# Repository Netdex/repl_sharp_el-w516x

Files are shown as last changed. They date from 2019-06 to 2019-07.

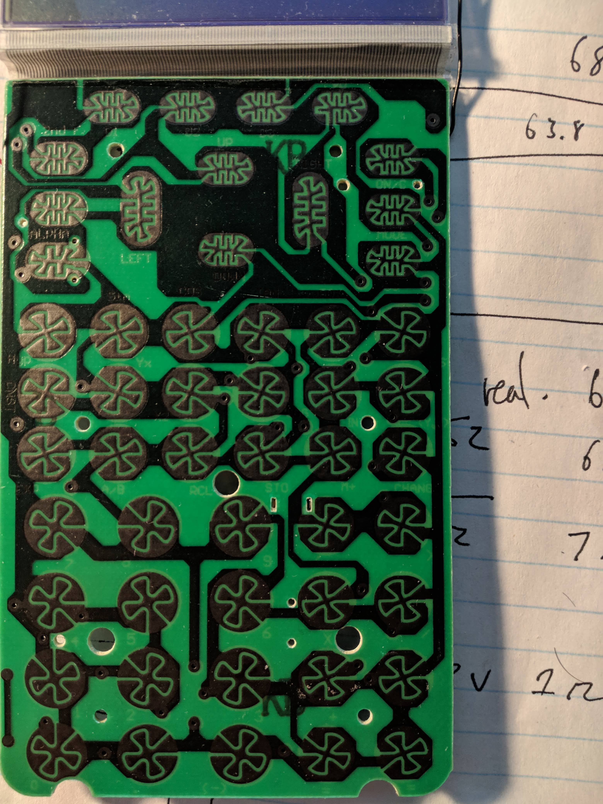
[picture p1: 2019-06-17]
IMG_20190607_183955.jpg

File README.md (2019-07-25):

# repl_sharp_el-w516x
`This project is a work-in-progress.`



## Overview
repl_sharp_el-w516x is a design for a replacement logic board for the SHARP EL-W516X calculator.



## Design
The goal of this project is to create a more powerful/elegant calculator out of as many components from the original 
calculator as possible.

This design reuses all components of the calculator except the following:
- Solar panel
  - It does not deliver enough power regardless
- Display
  - Connector pitch is too fine, and flex cable is too fragile
  - There are about 100 pins on the connector, and it requires a application-specific driver
  - The display is replaced with the [NHD-C12832A1Z-FSW-FBW-3V3](http://www.newhavendisplay.com/specs/NHD-C12832A1Z-FSW-FBW-3V3.pdf)
- PCB
- Battery
  - The original battery is an LR44 coin cell watch battery, which does not deliver the power required
  - The battery is replaced with a Samsung 3.8V Li-ion battery 

### Key matrix



The original calculator uses a carbon-coated silicone pad with carbon contacts on the PCB. This design uses the exact 
button pad footprint of the original calculator, with copper contacts instead.

The keys are arranged in a matrix, with a serial-in-parallel-out shift register on the rows, and a 
parallel-in-serial-out shift register on the columns. The microcontroller polls row and column pairs to detect 
key presses. Each column has a diode to avoid sinking 3V3 to GND when two buttons in the same row are pressed. 
In the case of multiple keys presed at once, ghosting will occur since diodes are only placed on a column-basis.

### Power delivery



The board is powered by a battery management IC with power path. The IC upregulates the battery voltage to +BATT + 250mV as VCC, 
where +BATT can vary from 3.0V (depleted) to 4.35V (full). An additional LDO regulates VCC to 3V3, which powers the 
microcontroller and other circuitry. The LDO has a dropout voltage of +250mV, which means that the battery will still 
have a bit of power left when it is depleted. The battery management IC actually charges to CV 4.2V, which means it 
will not charge the battery to full capacity (~80-90%).

The board can be charged via USB, which is also used for programming the microcontroller and other data transfer. 
Charging can occur while the device is being used, due to the power path management provided by the battery management 
IC. The battery charging current will automatically be ducked if the system power path draws too much power, to 
maintain system function. 

### uC
An ATMEGA32U4 microcontroller controls the display, input polling via shift registers, and computation. It is 
programmable via USB interface (factory ships with bootloader). ICSP is exposed via pads if required. 

Since the uC is powered by 3V3, an external 8 MHz oscillator provides the clock source.

## BOM
[InteractiveHtmlBom](https://raw.githack.com/Netdex/repl_sharp_el-w516x/master/kicad/bom/ibom.html)

## Pictures
3D Renders




Populated board (still covered in flux)



Front, in enclosure



Back, in enclosure (I need to file down the jagged edges)



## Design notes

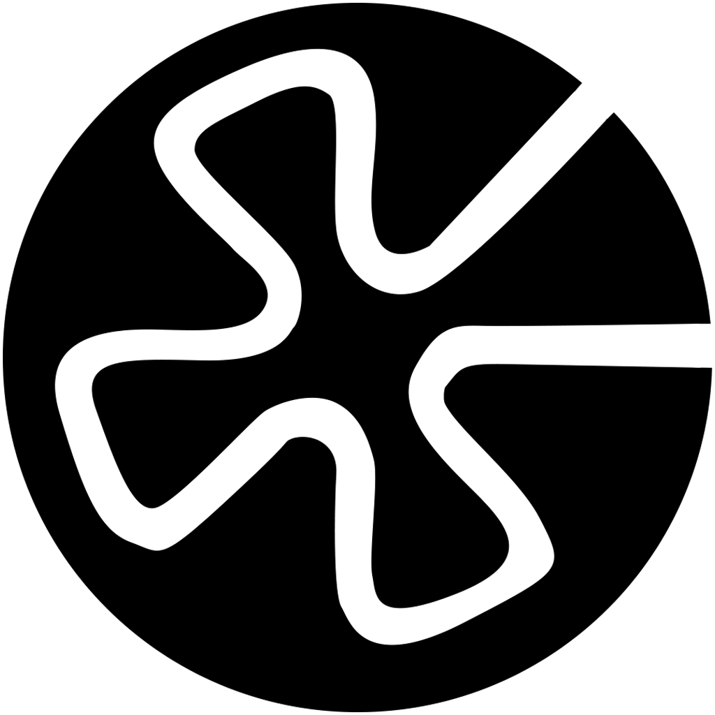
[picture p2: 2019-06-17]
btn_circular.png

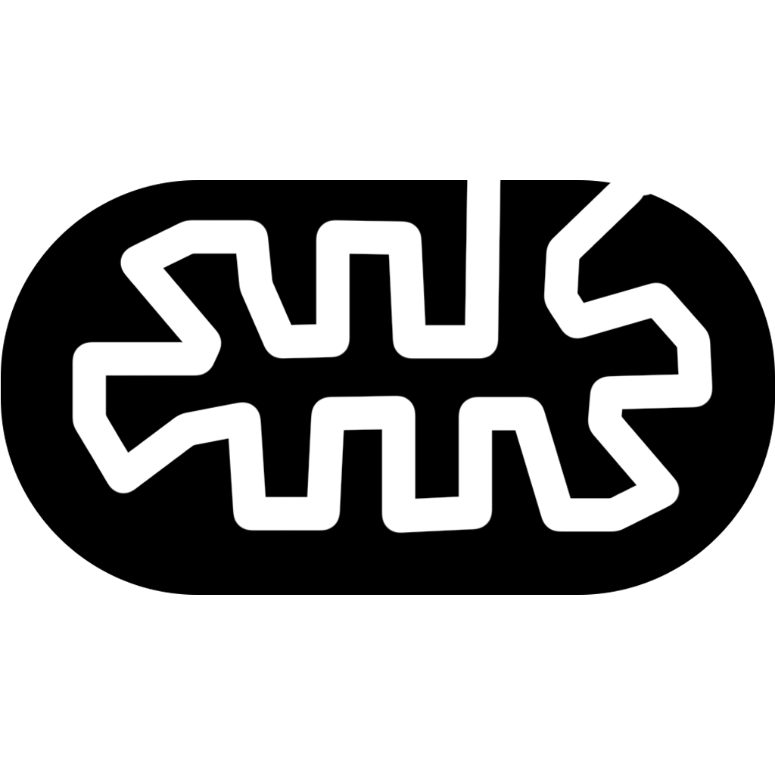
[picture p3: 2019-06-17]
btn_long_rect.png

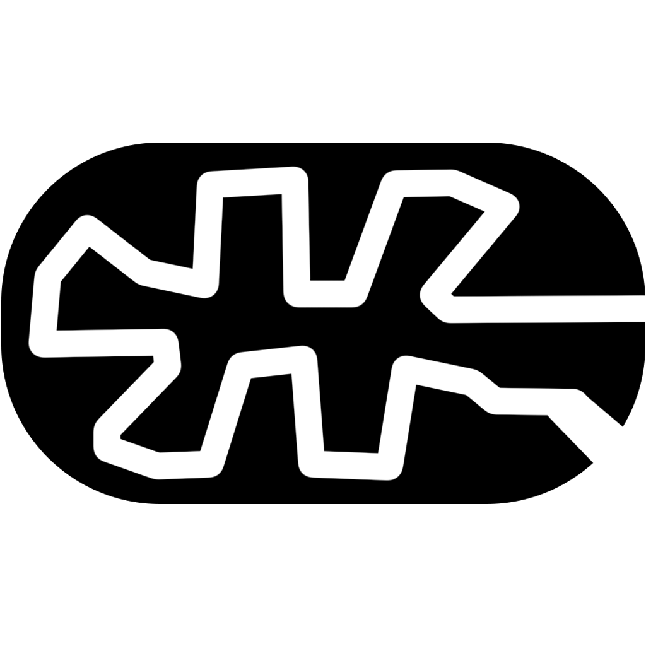
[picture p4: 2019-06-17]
btn_rect.png

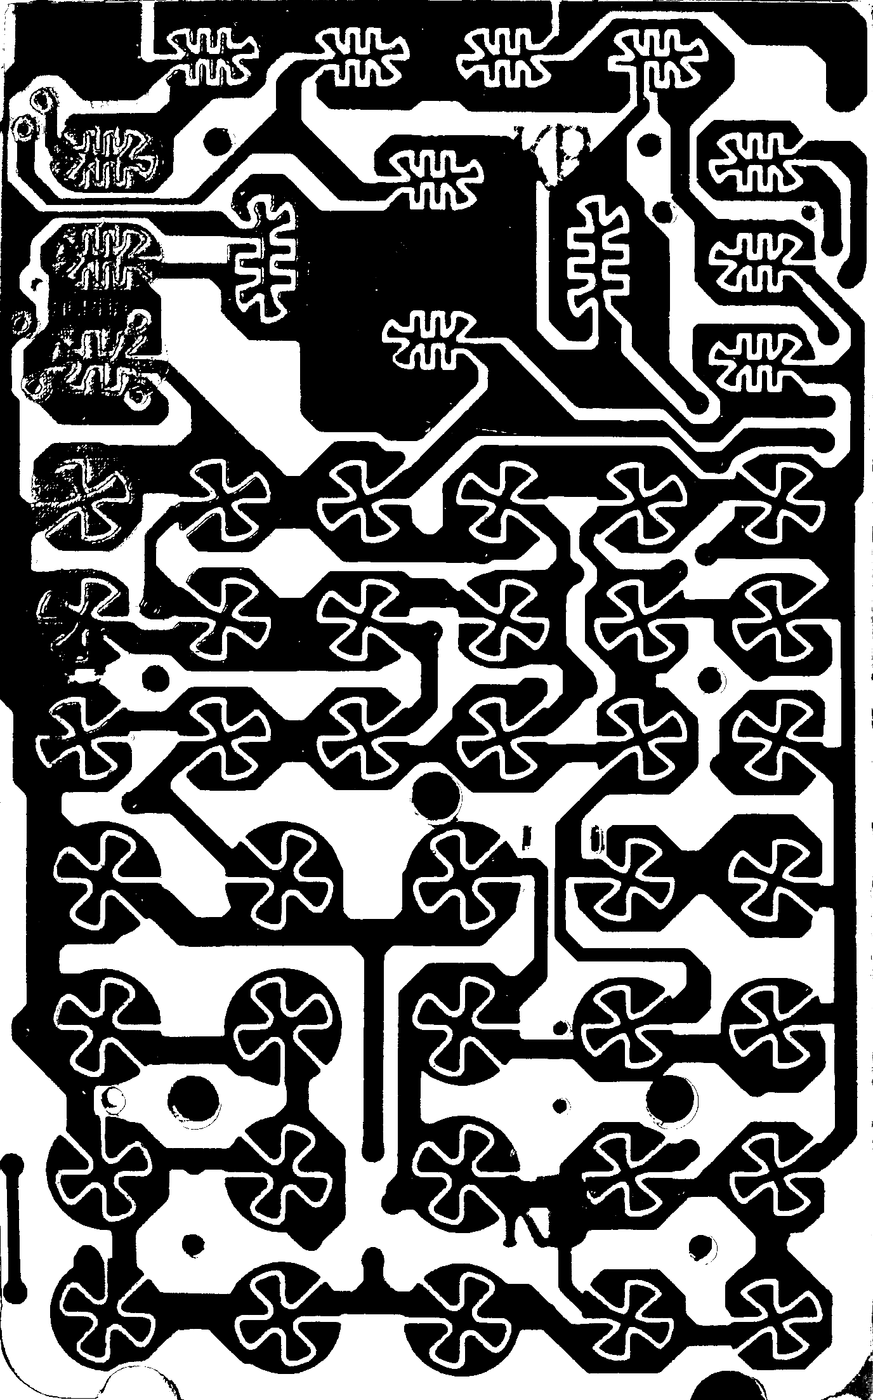
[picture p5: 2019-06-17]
board.png

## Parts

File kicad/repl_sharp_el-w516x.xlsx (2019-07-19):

Prj: | SHARP_EL-W516X |  |  |  |  | Board Qty: | 1
Co.: |  |  |  |  |  | Unit Cost: | CA$36.12
Prj date: | Sun 07 Jul 2019 11:28:35 PM EDT |  |  |  |  | Total Cost: | CA$36.12 |  |  |  | CA$36.12 | 25 of 34 parts found
$ date: | 2019-07-07 23:32:04
Global Part Info |  |  |  |  |  |  |  | Digi-Key
Refs | Value | Desc | Footprint | Manf# | Qty | Unit$ | Ext$ | Avail | Purch | Unit$ | Ext$ | Cat#
C1,C2 | 22p | Oscillator load | Capacitor_SMD:C_0603_1608Metric_Pad1.05x0.95mm_HandSolder | CC0603JRNPO9BN220 (http://www.yageo.com/documents/recent/UPY-GP_NP0_16V-to-50V_16.pdf) | 2 | CA$0.13 | CA$0.27 | 416000 |  | CA$0.13 | CA$0.27 | 311-1062-2-ND (https://octopart.com/click/track?ak=&sig=0b0acd0&sid=459&ppid=192915&vpid=119670960&ct=offers)
C12,C19,C21-C23 | 4.7u | USB power decoupling | Capacitor_SMD:C_0603_1608Metric_Pad1.05x0.95mm_HandSolder | CL10A475KQ8NNNC (http://www.samsungsem.com/kr/support/product-search/mlcc/CL10A475KQ8NNNC.jsp) | 5 | CA$0.13 | CA$0.67 | 3797320 |  | CA$0.13 | CA$0.67 | 1276-1045-6-ND (https://octopart.com/click/track?ak=&sig=00887e1&sid=459&ppid=10525435&vpid=72523742&ct=offers)
C20 | 10u | Power decoupling | Capacitor_SMD:CP_Elec_4x5.3 | UZR1C100MCL1GB | 1 | CA$0.81 | CA$0.81 | 4000 |  | CA$0.81 | CA$0.81 | 493-10106-2-ND (https://octopart.com/click/track?ak=&sig=0e8b655&sid=459&ppid=7874332&vpid=73993008&ct=offers)
C3,C4,C6-C8,C13-C18 | 0.1u | Assorted display | Capacitor_SMD:C_0603_1608Metric_Pad1.05x0.95mm_HandSolder | CL10B104KO8NNNC (http://www.samsungsem.com/kr/support/product-search/mlcc/CL10B104KO8NNNC.jsp) | 11 | CA$0.04 | CA$0.43 | 13894456 |  | CA$0.04 | CA$0.43 | 1276-1005-1-ND (https://octopart.com/click/track?ak=&sig=0d44439&sid=459&ppid=9267155&vpid=72523905&ct=offers)
C5,C9-C11 | 1u | Assorted decoupling | Capacitor_SMD:C_0603_1608Metric_Pad1.05x0.95mm_HandSolder | CL10A105KP8NNNC (http://www.samsungsem.com/kr/support/product-search/mlcc/CL10A105KP8NNNC.jsp) | 4 | CA$0.13 | CA$0.54 | 4338448 |  | CA$0.13 | CA$0.54 | 1276-1182-1-ND (https://octopart.com/click/track?ak=&sig=029fa32&sid=459&ppid=9291899&vpid=72523558&ct=offers)
D10 | LED_CHG | Indicator LED | LED_SMD:LED_0603_1608Metric_Pad1.05x0.95mm_HandSolder | SML-D12U1WT86 (https://www.rohm.com/datasheet/SML-D12U1W) | 1 | CA$0.30 | CA$0.30 | 90000 |  | CA$0.30 | CA$0.30 | SML-D12U1WT86TR-ND (https://octopart.com/click/track?ak=&sig=09c207e&sid=459&ppid=70850259&vpid=248817863&ct=offers)
D11 | LED | Indicator LED | Diode_SMD:D_0603_1608Metric_Pad1.05x0.95mm_HandSolder | SML-D12U1WT86 (https://www.rohm.com/datasheet/SML-D12U1W) | 1 | CA$0.30 | CA$0.30 | 90000 |  | CA$0.30 | CA$0.30 | SML-D12U1WT86TR-ND (https://octopart.com/click/track?ak=&sig=09c207e&sid=459&ppid=70850259&vpid=248817863&ct=offers)
D9 | LED_PGOOD | Indicator LED | LED_SMD:LED_0603_1608Metric_Pad1.05x0.95mm_HandSolder | SML-D12U1WT86 (https://www.rohm.com/datasheet/SML-D12U1W) | 1 | CA$0.30 | CA$0.30 | 90000 |  | CA$0.30 | CA$0.30 | SML-D12U1WT86TR-ND (https://octopart.com/click/track?ak=&sig=09c207e&sid=459&ppid=70850259&vpid=248817863&ct=offers)
D1-D8 | D | Switch matrix protection | Diode_SMD:D_0603_1608Metric_Pad1.05x0.95mm_HandSolder | TS4148C RZG (https://www.taiwansemi.com/products/datasheet/TS4148C_G1809.pdf) | 8 | CA$0.23 | CA$1.83 | 75000 |  | CA$0.23 | CA$1.83 | TS4148CRZGTR-ND (https://octopart.com/click/track?ak=&sig=0b15362&sid=459&ppid=22124138&vpid=462998877&ct=offers)
DS1 | NHD-C12832A1Z-FSW-FBW-3V3 | LCD Graphic Display Modules & Accessories FSTN (+) 41.4 x 24.3 x 4.0 | NHD-C12832A1Z-FSW-FBW-3V3:NHDC12832A1ZFSWFBW3V3 | NHD-C12832A1Z-FSW-FBW-3V3 (https://www.newhavendisplay.com/specs/NHD-C12832A1Z-FSW-FBW-3V3.pdf) | 1 | CA$14.80 | CA$14.80 | 3556 |  | CA$14.80 | CA$14.80 | NHD-C12832A1Z-FSW-FBW-3V3-ND (https://octopart.com/click/track?ak=&sig=0b8c610&sid=459&ppid=18786545&vpid=34235057&ct=offers)
J1 | USB_B_Micro | USB Micro B Amphenol | Connector_USB:USB_Micro-B_Amphenol_10103594-0001LF_Horizontal | 10118192-0001LF | 1 | CA$0.56 | CA$0.56 | 113400 |  | CA$0.56 | CA$0.56 | 609-4613-2-ND (https://octopart.com/click/track?ak=&sig=0da3005&sid=459&ppid=21265434&vpid=531263944&ct=offers)
J2 | AVR-ISP-6 |  | Connector_PinHeader_1.27mm:PinHeader_2x03_P1.27mm_Vertical_SMD |  | 1 | CA$0.00 | CA$0.00
JP1 | Jumper_2_Open |  | Jumper:SolderJumper-2_P1.3mm_Open_Pad1.0x1.5mm |  | 1 | CA$0.00 | CA$0.00
R1,R4-R13 | 10k | Input pull-down resistor | Resistor_SMD:R_0603_1608Metric_Pad1.05x0.95mm_HandSolder | RC0603FR-0710KL (http://www.yageo.com/documents/recent/PYu-RC_Group_51_RoHS_L_10.pdf) | 11 | CA$0.03 | CA$0.36 | 89267854 |  | CA$0.03 | CA$0.36 | 311-10.0KHRDKR-ND (https://octopart.com/click/track?ak=&sig=0e8a3be&sid=459&ppid=40025538&vpid=114982760&ct=offers)
R14,R15,R18 | 1k | LED current limiting | Resistor_SMD:R_0603_1608Metric_Pad1.05x0.95mm_HandSolder | RC0603FR-071KL (http://www.yageo.com/documents/recent/PYu-RC_Group_51_RoHS_L_10.pdf) | 3 | CA$0.13 | CA$0.40 | 50655000 |  | CA$0.13 | CA$0.40 | 311-1.00KHRTR-ND (https://octopart.com/click/track?ak=&sig=0f495f3&sid=459&ppid=55402882&vpid=188128908&ct=offers)
R16 | 1.13k | Battery Management ISET | Resistor_SMD:R_0603_1608Metric_Pad1.05x0.95mm_HandSolder | RC0603FR-071K13L (http://www.yageo.com/documents/recent/PYu-RC_Group_51_RoHS_L_10.pdf) | 1 | CA$0.13 | CA$0.13 | 640000 |  | CA$0.13 | CA$0.13 | 311-1.13KHRTR-ND (https://octopart.com/click/track?ak=&sig=00e18e1&sid=459&ppid=1225781&vpid=1706505&ct=offers)
R17 | 1.18k | Battery Management ILIM | Resistor_SMD:R_0603_1608Metric_Pad1.05x0.95mm_HandSolder | RC0603FR-071K18L (http://www.yageo.com/documents/recent/PYu-RC_Group_51_RoHS_L_10.pdf) | 1 | CA$0.13 | CA$0.13 | 190000 |  | CA$0.13 | CA$0.13 | 311-1.18KHRTR-ND (https://octopart.com/click/track?ak=&sig=078f9bb&sid=459&ppid=39797283&vpid=115141407&ct=offers)
R2,R3 | 22 | USB data resistor | Resistor_SMD:R_0603_1608Metric_Pad1.05x0.95mm_HandSolder | RC0603FR-0722RL (http://www.yageo.com/documents/recent/PYu-RC_Group_51_RoHS_L_10.pdf) | 2 | CA$0.13 | CA$0.27 | 4021914 |  | CA$0.13 | CA$0.27 | 311-22.0HRCT-ND (https://octopart.com/click/track?ak=&sig=02261b1&sid=459&ppid=1405859&vpid=115263523&ct=offers)
SW1 | SW_RESET | Reset button | Button_Switch_SMD:SW_Push_1P1T_NO_6x6mm_H9.5mm | PTS645SM43SMTR92 LFS (https://www.ckswitches.com/media/1471/pts645.pdf) | 1 | CA$0.22 | CA$0.22 | 369111 |  | CA$0.22 | CA$0.22 | CKN9112CT-ND (https://octopart.com/click/track?ak=&sig=0f7ff2f&sid=459&ppid=55389261&vpid=76879294&ct=offers)
SW12,SW28 | SW_Push |  | pcb_buttons:btn_long_rect |  | 2 | CA$0.00 | CA$0.00
SW66 | SW_POWER | Power switch | Button_Switch_SMD:SW_SPDT_CK-JS102011SAQN | JS102011SAQN (https://www.ckswitches.com/media/1422/js.pdf) | 1 | CA$0.75 | CA$0.75 | 24259 |  | CA$0.75 | CA$0.75 | 401-1999-1-ND (https://octopart.com/click/track?ak=&sig=0e387fb&sid=459&ppid=7088996&vpid=34441074&ct=offers)
SW3-SW5,SW10,SW18,SW19,SW21,SW26,SW34-SW37 | SW_Push |  | pcb_buttons:btn_rect |  | 12 | CA$0.00 | CA$0.00
SW6-SW9,SW14-SW17,SW22-SW25,SW30-SW33,SW38-SW47,SW50-SW55,SW58-SW63 | SW_Push |  | pcb_buttons:btn_circular |  | 38 | CA$0.00 | CA$0.00
TP1 | TP_VCC |  | TestPoint:TestPoint_Pad_1.0x1.0mm |  | 1 | CA$0.00 | CA$0.00
TP2 | TP_GND |  | TestPoint:TestPoint_Pad_1.0x1.0mm |  | 1 | CA$0.00 | CA$0.00
TP3 | TP_+BATT |  | TestPoint:TestPoint_Pad_1.0x1.0mm |  | 1 | CA$0.00 | CA$0.00
TP4 | TP_ICHG |  | TestPoint:TestPoint_Pad_1.0x1.0mm |  | 1 | CA$0.00 | CA$0.00
U1 | 74HC165D | 8-bit PISO Shift Register | Package_SO:SOIC-16_3.9x9.9mm_P1.27mm | 74HC165D,652 (https://assets.nexperia.com/documents/data-sheet/74HC_HCT165.pdf) | 1 | CA$0.51 | CA$0.51 | 9860 |  | CA$0.51 | CA$0.51 | 1727-3782-ND (https://octopart.com/click/track?ak=&sig=0c27404&sid=459&ppid=78737090&vpid=417193082&ct=offers)
U2 | ATmega32U4-AU | ATMEGA32U4-AU uC | Package_QFP:TQFP-44_10x10mm_P0.8mm | ATMEGA32U4-AUR | 1 | CA$5.65 | CA$5.65 | 4484 |  | CA$5.65 | CA$5.65 | ATMEGA32U4-AURDKR-ND (https://octopart.com/click/track?ak=&sig=060b535&sid=459&ppid=77760311&vpid=408717064&ct=offers)
U3 | 74HC595 | 8-bit SIPO Shift Register | Package_SO:SOIC-16_3.9x9.9mm_P1.27mm | SN74HC595DR (http://www.ti.com/lit/ds/symlink/sn74hc595.pdf) | 1 | CA$0.69 | CA$0.69 | 47324 |  | CA$0.69 | CA$0.69 | 296-14857-6-ND (https://octopart.com/click/track?ak=&sig=0816528&sid=459&ppid=500634&vpid=1131053&ct=offers)
U4 | BQ24072RGTR | IC LI-ION Charge Mgmt | UL_BQ24072RGTR:BQ24072RGTR | BQ24072RGTR | 1 | CA$3.05 | CA$3.05 | 3000 |  | CA$3.05 | CA$3.05 | 296-38871-2-ND (https://octopart.com/click/track?ak=&sig=056bd39&sid=459&ppid=12192001&vpid=188081820&ct=offers)
U5 | AP2210-33 | Linear Voltage Reg IC Positive Fixed 1 Output 300mA | Package_TO_SOT_SMD:SOT-23 | AP2210N-3.3TRG1 (http://www.diodes.com/datasheets/AP1117.pdf) | 1 | CA$0.56 | CA$0.56 | 84000 |  | CA$0.56 | CA$0.56 | AP2210N-3.3TRG1DITR-ND (https://octopart.com/click/track?ak=&sig=07a2e74&sid=459&ppid=30954633&vpid=94944143&ct=offers)
XB1 | BATT_CONN | Right Angle SMT Battery Conn | 009155004541006:BAT_009155004541006 | 009155004541006 (https://media.digikey.com/pdf/Data%20Sheets/AVX%20PDFs/9155%20MOBO%20Battery%20Connector.pdf) | 1 | CA$1.67 | CA$1.67 | 35000 |  | CA$1.67 | CA$1.67 | 478-5452-2-ND (https://octopart.com/click/track?ak=&sig=07d7e9d&sid=459&ppid=19037771&vpid=33587679&ct=offers)
Y1 | Crystal | 8MHz ±20ppm Crystal 18pF 100 Ohms 2-SMD | Crystal:Crystal_SMD_5032-2Pin_5.0x3.2mm | ECS-80-18-30-JGN-TR (http://www.ecsxtal.com/store/pdf/ecx-53r.pdf) | 1 | CA$0.93 | CA$0.93 | 7000 |  | CA$0.93 | CA$0.93 | XC2103TR-ND (https://octopart.com/click/track?ak=&sig=0e3994e&sid=459&ppid=71168052&vpid=252370608&ct=offers)
 | Used currency rates: |  |  |  |  | Total Purchase: | CA$0.00 |  |  |  | CA$0.00
 | CAD(CA$)/USD($): | 1.345169061
KiCost® v.1.1

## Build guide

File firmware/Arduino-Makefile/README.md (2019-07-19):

# A Makefile for Arduino Sketches 

This is a very simple Makefile which knows how to build Arduino sketches. It defines entire workflows for compiling code, flashing it to Arduino and even communicating through Serial monitor. You don't need to change anything in the Arduino sketches.

## Features

- Very robust
- Highly customizable
- Supports all official AVR-based Arduino boards
- Supports official ARM-based Arduino boards using Atmel SAM chip family
and includes on-device debugging targets.
- Supports chipKIT
- Supports Teensy 3.x (via Teensyduino)
- Works on all three major OS (Mac, Linux, Windows)
- Auto detects serial baud rate and libraries used
- Support for `*.ino` and `*.pde` sketches as well as raw `*.c` and `*.cpp`
- Support for Arduino Software versions 0.x, 1.0.x, 1.5.x and 1.6.x except 1.6.2.
We recommend 1.6.3 or above version of Arduino IDE.
- Automatic dependency tracking. Referred libraries are automatically included
in the build process. Changes in `*.h` files lead to recompilation of sources which include them

## Installation

### Through package

#### Using apt-get (or aptitude)

If you're using FreeBSD, Debian, Raspbian or Ubuntu, you can find this in the `arduino-mk`
package which can be installed using `apt-get` or `aptitude`.

```sh
sudo apt-get install arduino-mk
```

#### homebrew (or linuxbrew)

If you're using homebrew (or [linuxbrew](https://github.com/Homebrew/linuxbrew)) then you can find this in the
`arduino-mk` package which can be installed using the following commands.

Also make sure you have the necessary dependencies installed. Refer to the [Requirements](#requirements) section below to install the dependencies.

```sh
# add tap
$ brew tap sudar/arduino-mk

# to install the last stable release
$ brew install arduino-mk

# to install the development version
$ brew install --HEAD arduino-mk
```

#### Arch Linux

Arch Linux users can use the unofficial AUR package [arduino-mk](https://aur.archlinux.org/packages/arduino-mk/).
It can be installed with [AUR] helper using the following command.

```sh
yay -S arduino-mk
```

#### Fedora

Fedora Linux users can use our packaging instructions [here](https://github.com/sudar/Arduino-Makefile/tree/master/packaging/fedora)
to build an RPM.

### From source

- Download the latest release
- Or clone it from Github using the command `git clone git@github.com:sudar/Arduino-Makefile.git`
- Check the [usage section](https://github.com/sudar/Arduino-Makefile#usage) in this readme about setting usage options

## Requirements

### Arduino IDE

You need to have the Arduino IDE. You can either install it through the
installer or download the distribution zip file and extract it.

### pySerial

The Makefile also delegates resetting the board to a short Python program.
You'll need to install [`pySerial`](https://pypi.python.org/pypi/pyserial) to use it though.

On most systems you should be able to install it using either `pip` or `easy_install`.

```sh
pip install pyserial

# or if you prefer easy_install

easy_install -U pyserial
```

If you prefer to install it as a package, then you can do that as well.

On Debian or Ubuntu:

```sh
apt-get install python-serial
```

On Fedora:

```sh
yum install pyserial

# or on Fedora 22+

dnf install pyserial
```

On openSUSE:

```sh
zypper install python-serial
```

On Arch:

```sh
sudo pacman -S python-pyserial
```

On Mac using MacPorts:

```sh
sudo port install py27-serial
```

On Windows:

You need to install Cygwin and its packages for Make, Perl and the following Serial library.

Assuming you included Python in your Cygwin installation:

1. download PySerial source package from [https://pypi.python.org/pypi/pyserial](https://pypi.python.org/pypi/pyserial)
2. extract downloaded package running `tar xvzf dowloaded_package_name.tar.gz`
3. navigate to extracted package folder
4. build and install Python module: 
 
```
python setup.py build
python setup.py install
```

Alternatively, if you have setup Cygwin to use a Windows Python installation,
simply install using pip:

```
pip install pyserial
```

Arduino-Makefile should automatically detect the Python installation type and
use the correct device port binding.

## Usage

Download a copy of this repo somewhere to your system or install it through a package by following the above installation instruction.

Sample makefiles are provided in the `examples/` directory.  E.g. [Makefile-example](examples/MakefileExample/Makefile-example.mk) demonstrates some of the more advanced options,
whilst [Blink](examples/Blink/Makefile) demonstrates the minimal settings required for various boards like the Uno, Nano, Mega, Teensy, ATtiny etc.

### Mac

On the Mac with IDE 1.0 you might want to set:

```make
    ARDUINO_DIR   = /Applications/Arduino.app/Contents/Resources/Java
    ARDMK_DIR     = /usr/local
    AVR_TOOLS_DIR = /usr
    MONITOR_PORT  = /dev/ttyACM0
    BOARD_TAG     = mega2560
```

On the Mac with IDE 1.5+ it's like above but with

```make
    ARDUINO_DIR   = /Applications/Arduino.app/Contents/Java
```
### Linux

You can either declare following variables in your project's makefile or set them as environmental variables.

```make
    ARDUINO_DIR – Directory where Arduino is installed
    ARDMK_DIR – Directory where you have copied the makefile
    AVR_TOOLS_DIR – Directory where avr tools are installed
```

Keep in mind, that Arduino 1.5.x+ comes with it's own copy of avr tools which you can leverage in your build process here.

Example of  ~/.bashrc file:

```make
    export ARDUINO_DIR=/home/sudar/apps/arduino-1.0.5
    export ARDMK_DIR=/home/sudar/Dropbox/code/Arduino-Makefile
    export AVR_TOOLS_DIR=/usr/include
```

Example of the project's make file:

```make
    BOARD_TAG     = mega2560
    MONITOR_PORT  = /dev/ttyACM0
```

### Windows

On Windows (using Cygwin), you might want to set:

```make
    # Symbolic link to Arduino installation directory - see below
    ARDUINO_DIR   = C:/Arduino
    ARDMK_DIR     = path/to/mkfile
    MONITOR_PORT  = com3
    BOARD_TAG     = mega2560
```

**NOTE: Use forward slash not backslash and there should be no spaces or
special characters in the Windows paths (due to Win/Unix crossover). The paths
should not be *cygdrive* paths.**

On Windows (using MSYS and PuTTY), you might want to set the following extra parameters:

```make
    MONITOR_CMD   = putty
    MONITOR_PARMS = 8,1,n,N
```

On Arduino 1.5+ installs, you should set the architecture to either `avr` or `sam` and if using a submenu CPU type, then also set that:

```make
    ARCHITECTURE  = avr
    BOARD_TAG     = atmegang
    BOARD_SUB     = atmega168
```

#### Symbolic Link

It is recommended in Windows that you create a symbolic link to avoid problems with file naming conventions on Windows; unless one installs to a non-default location. For example, if your your Arduino directory is in:

    C:\Program Files (x86)\Arduino

You will get problems with the special characters on the directory name. More details about this can be found in [issue #94](https://github.com/sudar/Arduino-Makefile/issues/94)

To create a symbolic link, you can use the command “mklink” on Windows, e.g.

```sh
mklink /d C:\Arduino C:\Program Files (x86)\Arduino
```
Alternatively if you've setup Cygwin hard symbolic links ([CYGWIN=winsymlinks:native](https://www.cygwin.com/cygwin-ug-net/using-cygwinenv.html)):

```sh
ln -s /cygdrive/c/Program Files\ \(x86\)/Arduino/ C:/Arduino
```

After which, the variables should be:

```make
    ARDUINO_DIR=C:/Arduino
```

Instead of:

```make
    ARDUINO_DIR=C:/Program\ Files\ \(x86\)/Arduino
```

### Useful Variables

The list of all variables that can be overridden is available at [arduino-mk-vars.md](arduino-mk-vars.md) file.

- `BOARD_TAG` - Type of board, for a list see boards.txt or `make show_boards`
- `MONITOR_PORT` - The port where your Arduino is plugged in, usually `/dev/ttyACM0` or `/dev/ttyUSB0` in Linux or Mac OS X and `com3`, `com4`, etc. in Windows.
- `ARDUINO_DIR` - Path to Arduino installation. Using Windows with Cygwin,
  this path must use Unix / and not Windows \\ (eg "C:/Arduino" not
  "C:\\Arduino).
- `ARDMK_DIR`   - Path where the `*.mk` are present. If you installed the package, then it is usually `/usr/share/arduino`. On Windows, this should be a path without spaces and no special characters, it can be a *cygdrive* path if necessary and must use / not \\.
- `AVR_TOOLS_DIR` - Path where the avr tools chain binaries are present. If you are going to use the binaries that came with Arduino installation, then you don't have to set it. Otherwise set it relative and not absolute.

## Including Libraries

You can specify space separated list of libraries that are needed for your sketch in the variable `ARDUINO_LIBS`.

```make
	ARDUINO_LIBS = Wire SoftwareSerial
```

The libraries will be searched for in the following places in the following order.

- `/libraries` directory inside your sketchbook directory. Sketchbook directory will be auto detected from your Arduino preference file. You can also manually set it through `ARDUINO_SKETCHBOOK`.
- `/libraries` directory inside your Arduino directory, which is read from `ARDUINO_DIR`.

The libraries inside user directories will take precedence over libraries present in Arduino core directory.

The makefile can autodetect the libraries that are included from your sketch and can include them automatically. But it can't detect libraries that are included from other libraries. (see [issue #93](https://github.com/sudar/Arduino-Makefile/issues/93))

## avrdude

To upload compiled files, `avrdude` is used. This Makefile tries to find `avrdude` and it's config (`avrdude.conf`) below `ARDUINO_DIR`. If you like to use the one installed on your system instead of the one which came with Arduino, you can try to set the variables `AVRDUDE` and `AVRDUDE_CONF`. On a typical Linux system these could be set to

```make
      AVRDUDE      = /usr/bin/avrdude
      AVRDUDE_CONF = /etc/avrdude.conf
```

## Teensy 3.x

For Teensy 3.x support you must first install [Teensyduino](http://www.pjrc.com/teensy/teensyduino.html).

See examples/BlinkTeensy for example usage.

## Robotis OpenCM

For Robotis OpenCM support you must first install [the OpenCM IDE](http://support.robotis.com/en/software/robotis_opencm/robotis_opencm.htm)

See examples/BlinkOpenCM for example usage.

For large Robotis projects, [libmaple](https://github.com/Rhoban/Maple) may be more appropriate, as the OpenCM IDE uses a very old compiler release.

## Arduino ARM Boards

For Arduino boards using ARM architechure, specifically the Atmel SAM series
((SAM3X8E) Due; (SAMD21) Arduino M0 [Pro], Zero, MKR1000, Feather M0, etc.), first
install the board support package from the IDE or other distribution channels.

Define`ARDUINO_PACKAGE_DIR` as the root path containing the ARM support
package (the manufacturer folder) and the `BOARD_TAG` (see `make show_boards`
for help) within your project Makefile. Include 'Sam.mk' rather than
  'Arduino.mk' at the end of your file - see examples/ZeroBlink,
  examples/MZeroBlink and examples/DueBlink for example usage.

**Note**: The Arduino IDE does not install board support packages to
the base Arduino installation directory (the directory that will work with AVR
Makefiles). They are generally installed to a '.arduino15/packages' folder in
the users home directory. This is the reason for the new `ARDUINO_PACKAGE_DIR`
define. On Windows, the package directory is often in the user home directory
so advice is to create a symblic link to avoid slash/space in path problems.
You can also manually install support packages in your Sketchbook 'hardware'
folder, then define ARDUINO_PACKAGE_DIR as this path.

If using a SAM board from a manufacturer other than Arduino, one must still
install the Arduino board support as above (unless using externally defined
toolchain) and then define the location of the manufacturer board support core
using the ALTERNATIVE_CORE_PATH define. For example: `ALTERNATE_CORE_PATH =
$(ARDUINO_SKETCHBOOK)/hardware/sparkfun/samd`

The programing method will auto-detect based on the `BOARD_TAG` settings read
from boards.txt:

Programming using OpenOCD CMSIS-DAP with the Programming/debug USB is
currently supported (the same method used by the IDE), including burning
bootloaders. External CMSIS tools such as Atmel Ice will also work with this
method. Black Magic Probe (BMP) support is also included using GDB for both
uploading and debugging.

Native USB programing using Bossa (Due, Zero, MKR1000, Feather style bootloaders)
and avrdude (M0 bootloaders) is supported. The bootloaders on these devices
requires a double press of the reset button or open/closing the serial port at
1200 BAUD. The automatic entry of the bootloader is attempted using
`ard-reset-arduino` when using the general `make upload` target by polling
attached devices until the bootloader port re-attaches (same method as the
IDE). On Windows, the USB enumerates as differnt COM ports for the CDC Serial
and bootloader and these must be defined. On encountering problems, one can
manually enter the bootloader then upload using the `make raw_upload` target.
Note that the `make reset` target will enter the bootloader on these devices;
there is no way to reset over USB.

If using system installed tools, be aware that `openocd` and `bossa` were
orginally forked for Arduino support and system distributions may not be up
to date with merged changes. `bossa` must be version 1.7->. `openocd` should
work but there may be problems at run time
[ref](https://github.com/pda/arduino-zero-without-ide). Ideally, use the
support packaged version or compile and install the Arduino fork.

With the ARM chipset and using a CMSIS-DAP tool, on-device debugging is made available:

* `debug_init` and `debug` targets for on-device debugging using GDB. To use
  this, one must start the GDB server with `make debug_init &`, followed by
  connecting to the target with `make debug`. If using a Black Magic Probe,
  one can just use `make debug`. At the moment, a system wide `arm-none-eabi-gdb` must be
  installed as the one supplied with the Arduino toolchain
  does not appear to work. 
* Example usage: https://asciinema.org/a/Jarz7Pr3gD6mqaZvCACQBzqix
* See the examples/MZeroBlink Makefile for a commented example.

## Versioning

The current version of the makefile is `1.6.0`. You can find the full history in the [HISTORY.md](HISTORY.md) file

This project adheres to Semantic [Versioning 2.0](http://semver.org/).

## License

This makefile and the related documentation and examples are free software; you can redistribute it and/or modify it
under the terms of the GNU Lesser General Public License as
published by the Free Software Foundation; either version 2.1 of the License, or (at your option) any later version.

## Contribution

All contributions (even documentation) are welcome :) Open a pull request and I would be happy to merge them.
Also checkout the [contribution guide](CONTRIBUTING.md) for more details.

If you are looking for ideas to work on, then check out the following TODO items or the [issue tracker](https://github.com/sudar/Arduino-Makefile/issues/).

## Limitations / Known Issues / TODO's

- Since it doesn't do any pre processing like Arduino IDE, you have to declare all methods before you use them ([issue #59](https://github.com/sudar/Arduino-Makefile/issues/59))
- More than one .ino or .pde file is not supported yet ([issue #49](https://github.com/sudar/Arduino-Makefile/issues/49))
- When you compile for the first time, it builds all libs inside Arduino directory even if it is not needed. But while linking only the relevant files are linked. ([issue #29](https://github.com/sudar/Arduino-Makefile/issues/29)). Even Arduino IDE does the same thing though.
- This makefile doesn't support boards or IDE from Arduino.org.

If you find an issue or have an idea for a feature then log them in the [issue tracker](https://github.com/sudar/Arduino-Makefile/issues/)

## Interfacing with other projects/frameworks/IDE's

### Colorgcc

It is possible to use [`colorgcc`](https://github.com/colorgcc/colorgcc) with this makefile. Check out [this comment](http://hardwarefun.com/tutorials/compiling-arduino-sketches-using-makefile#comment-1408) to find usage instructions.

### Emacs/Flymake support

On-the-fly syntax checking in Emacs using the [Flymake](http://www.emacswiki.org/emacs/FlyMake) minor mode is now possible.

First, the flymake mode must be configured to recognize ino files :

Edit the flymake configuration :

```
    M-x customize-option RET
    flymake-allowed-file-name-masks RET
```

Add the line :

```
      ("\\.ino\\'" flymake-simple-make-init)
```

Then click on "Apply and Save" button

Then, the following line must be added to the project Makefile :

```make
    check-syntax:
        $(CXX) -c -include Arduino.h   -x c++ $(CXXFLAGS)   $(CPPFLAGS)  -fsyntax-only $(CHK_SOURCES)
```

### Code:Blocks integration

In Code:Blocks open Project -> Properties -> Project settings tab -> check "This is custom Makefile".

Now go to Settings -> Environment -> Environment variables -> Add

Add three keys with paths as values, using full paths (!):

```make
	ARDUINO_DIR=/full/path/to/arduino-1.0.6
	ARDMK_DIR=/full/path/to/sketchbook
	AVR_TOOLS_DIR=/usr
```

Now to set DEBUG target (this will compile the project) go to Build options -> Debug -> "Make" commands

In Build Project/Target remove $target:

```sh
$make -f $makefile
```

In Clean Project/Target remove $target:

```sh
$make -f $makefile clean
```

To set the RELEASE target (which will compile and upload) go to Build options -> Release -> "Make" commands

In Build Project/Target put:

```sh
$make -f $makefile upload
```

In Clean Project/Target remove $target:

```sh
$make -f $makefile clean
```

## Test Suite

This project includes a suite of example Makefiles and small Arduino and chipKIT
programs to assist the maintainers of the Makefile. Run
`tests/script/bootstrap.sh` to attempt to automatically install the dependencies
(Arduino IDE, MPIDE, etc.). Run `tests/script/runtests.sh` to attempt to compile
all of the examples. The bootstrap script is primarily intended for use by a
continuous integration server, specifically Travis CI. It is not intended for
normal users.

## Makefile Generator and Project Initialisation

`ardmk-init` within the bin/ folder is a utility Python script to create a
Arduino-mk Makefile for a project and also has option to create a traditional *tree*
organization (src, lib, bin). It can be used as with commanline arguments or
prompted - see examples below (append `$ARDMK_DIR/bin/` to command if not on path):

* Run prompted within current working directory: `ardmk-init`
* Create Arduino Uno Makefile (useful within a library example): `ardmk-init -qb uno`
* Create boilerplate Arduino Uno project in current working directory of same
  name: `ardmk-init -b uno --quiet --project`
* Create Arduino-mk nano Makefile in current working directory with template .ino: `ardmk-init -b nano -u atmega328 -qtn my-project`
* See `ardmk-init --help` for more.

### Bare-Arduino–Project

If you are planning on using this makefile in a larger/professional project, you might want to take a look at the [Bare-Arduino–Project](https://github.com/WeAreLeka/Bare-Arduino-Project) framework.

Similar to HTML frameworks, [Bare-Arduino–Project](https://github.com/WeAreLeka/Bare-Arduino-Project) aims at providing a basic `tree` organization, `Makefile` configurations for both OS X and Linux and a handful of instruction on how to get started with a robust Arduino project architecture.

Further information are available in the [README.md](https://github.com/WeAreLeka/Bare-Arduino-Project/blob/master/README.md) as well as in the [use/installation procedure](https://github.com/WeAreLeka/Bare-Arduino-Project/blob/master/INSTALL.md).

Please be sure to report issues to [Bare-Arduino–Project](https://github.com/WeAreLeka/Bare-Arduino-Project/issues) if you use it instead of this project.

## Credits

This makefile was originally created by [Martin Oldfield](http://mjo.tc/atelier/2009/02/arduino-cli.html) and he maintained it till v0.10.2.
From May 2013, it is maintained by [Sudar Muthu](http://hardwarefun.com/tutorials/compiling-arduino-sketches-using-makefile) and [Simon John](https://github.com/sej7278) with the help of [40+ contributors](https://github.com/sudar/Arduino-Makefile/graphs/contributors).

## Similar works
- It's not a derivative of this, but Alan Burlison has written a [similar thing](http://bleaklow.com/2010/06/04/a_makefile_for_arduino_sketches.html).
- Alan's Makefile was used in a [Pragmatic Programmer's article](http://pragprog.com/magazines/2011-04/advanced-arduino-hacking).
- Rei Vilo wrote to tell me that he's using the Makefile ina Xcode 4 template called [embedXcode](http://embedxcode.weebly.com/). Apparently it supports many platforms and boards, including AVR-based Arduino, AVR-based Wiring, PIC32-based chipKIT, MSP430-based LaunchPad and ARM3-based Maple.

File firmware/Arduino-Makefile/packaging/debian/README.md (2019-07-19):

# How to compile a Deb package

Use these instructions to build your own Deb package from your local sources.
For the latest official packages go to [Debian](http://packages.debian.org/arduino-mk)
or [Ubuntu](https://launchpad.net/ubuntu/+source/arduino-mk) or use apt.

First install the dependencies as root:

    apt-get build-dep arduino-mk
    apt-get install arduino-core build-essential dpkg-dev fakeroot devscripts

Fetch the Debian source:

    apt-get source arduino-mk

Make any local changes to want within the arduino-mk-* directory and update the package version:

    cd arduino-mk-*
    dch -i

Then compile. This will create a binary Deb:

    dpkg-buildpackage -b

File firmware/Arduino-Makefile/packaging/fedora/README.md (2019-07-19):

# How to compile an RPM

First install the dependencies as root:

```sh
    yum install arduino-core rpm-build

    # or on Fedora 22+

    dnf install arduino-core rpmdevtools
```

From the top-level Arduino-Makefile directory you've checked out of github, run the following (as unprivileged user) to create a compressed tarball using the naming conventions required by rpmbuild:

    git archive HEAD --prefix=arduino-mk-1.5/ -o ../arduino-mk-1.5.tar.gz

If you don't already have a rpmbuild setup (e.g. you've not installed the SRPM) you will need to create the directories:

    mkdir -p ~/rpmbuild/{SOURCES,SPECS}

Then copy the tarball and specfile into those directories:

    cp ../arduino-mk-1.5.tar.gz ~/rpmbuild/SOURCES/
    cp packaging/fedora/arduino-mk.spec ~/rpmbuild/SPECS/

Then compile. This will create a binary and source RPM:

    cd ~/rpmbuild/SPECS/
    rpmbuild -ba arduino-mk.spec

Fedora's AVR compilers use ccache, so you may have to override some of the paths to the AVR tools in your sketch's Makefile, for example:

```Makefile
OVERRIDE_EXECUTABLES = 1
CC      = /usr/lib64/ccache/$(CC_NAME)
CXX     = /usr/lib64/ccache/$(CXX_NAME)
AS      = /usr/bin/$(AS_NAME)
OBJCOPY = /usr/bin/$(OBJCOPY_NAME)
OBJDUMP = /usr/bin/$(OBJDUMP_NAME)
AR      = /usr/bin/$(AR_NAME)
SIZE    = /usr/bin/$(SIZE_NAME)
NM      = /usr/bin/$(NM_NAME)
```

Or if you don't want to use ccache, then just set ```AVR_TOOLS_PATH=/usr``` and none of the above will be necessary.

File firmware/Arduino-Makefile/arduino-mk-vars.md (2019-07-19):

# Documentation of variables

The following are the different variables that can be overwritten in the user makefiles.

*	[Global variables](#global-variables)
*	[Installation/Directory variables](#installationdirectory-variables)
*	[Arduino IDE variables](#arduino-ide-variables)
*	[Sketch related variables](#sketch-related-variables)
*	[ISP programming variables](#isp-programming-variables)
*	[Compiler/Executable variables](#compilerexecutable-variables)
*	[Avrdude setting variables](#avrdude-setting-variables)
*	[Bootloader variables](#bootloader-variables)
*	[ChipKIT variables](#chipkit-variables)
*	[ARM variables](#arm-variables)
*	[Ctags variables](#ctags-variables)

## Global variables

### ARDUINO_QUIET

**Description:**

Suppress printing of Arduino-Makefile configuration.

Defaults to `0` (unset/disabled).

**Example:**

```Makefile
ARDUINO_QUIET = 1
```

**Requirement:** *Optional*

----

## Installation/Directory variables

### ARDMK_DIR

**Description:**

Directory where the `*.mk` files are stored.

Usually can be auto-detected as parent of `Arduino.mk`.

**Example:**

```Makefile
ARDMK_DIR = /usr/share/arduino
```

**Requirement:** *Optional*

----

### AVR_TOOLS_DIR

**Description:**

Directory where tools such as `avrdude`, `avr-g++`, `avr-gcc`, etc. are stored in the `bin/` subdirectory.

Usually can be auto-detected from `$PATH` as `SYSTEMPATH_AVR_TOOLS_DIR` or as `BUNDLED_AVR_TOOLS_DIR` within the Arduino distribution.

**Example:**

```Makefile
AVR_TOOLS_DIR = /usr
# or
AVR_TOOLS_DIR = /usr/share/arduino/hardware/tools/avr
```

**Requirement:** *Optional*

----

### ARM_TOOLS_DIR

**Description:**

Directory where the arm toolchain is installed. `arm-none-eabi-*` should be
within a /bin subdirectory.

Can usually be detected from `$ARDUINO_PACKAGE_DIR` /tools subdirectory when ARM
device support is installed.

**Example:**

```Makefile
ARM_TOOLS_DIR = /usr
# or
ARM_TOOLS_DIR =
/usr/share/arduino/hardware/tools/arm-none-eabi-gcc/VERSION
```

**Requirement:** *Optional*

----

### RESET_CMD

**Description:**

Command to reset the MCU.

Defaults to `ard-reset-arduino` with the extra `--caterina` flag for atmega32u4 boards.

**Example:**

```Makefile
RESET_CMD = $(HOME)/gertduino/reset
```

**Requirement:** *Optional*

----

## Arduino IDE variables

### ARDUINO_DIR

**Description:**

Directory where the Arduino IDE and/or core files are stored. Usually can be auto-detected as `AUTO_ARDUINO_DIR`.

**Example:**

```Makefile
# Linux
ARDUINO_DIR = /usr/share/arduino
# Mac OS X
ARDUINO_DIR = /Applications/Arduino.app/Contents/Resources/Java
# Mac OSX with IDE 1.5+
ARDUINO_DIR = /Applications/Arduino.app/Contents/Java
```

**Requirement:** *Optional*

----

### ARDUINO_PACKAGE_DIR

**Description:**

Directory where the Arduino package support files are stored. Can auto-detect based on default OS IDE locations.

**Example:**

```Makefile
# Linux
ARDUINO_PACKAGE_DIR = $(HOME)/.arduino15/packages
# Mac OS X
ARDUINO_PACKAGE_DIR = $(HOME)/Library/Arduino15/packages
# Windows
ARDUINO_PACKAGE_DIR = $(USERPROFILE)/AppData/Local/Arduino15/packages
```

**Requirement:** *Optional*

----

### ARDUINO_PLATFORM_LIB_PATH

**Description:**

Directory where the Arduino platform dependent libraries are stored.
(Used only for Arduino 1.5+)

**Example:**

```Makefile
ARDUINO_PLATFORM_LIB_PATH = /usr/share/arduino/hardware/arduino/avr/libraries
```

**Requirement:** *Optional*

----

### ARDUINO_VERSION

**Description:**

Version string for Arduino IDE and/or core.

Usually can be auto-detected as `AUTO_ARDUINO_VERSION` from `/usr/share/arduino/lib/version.txt`

**Example:**

```Makefile
ARDUINO_VERSION = 105
```

**Requirement:** *Optional*

----

### ARCHITECTURE

**Description:**

Architecture for Arduino 1.5+

Defaults to unset for 1.0 or `avr` for 1.5+. This value is not literally the chip architecture but will often be
the chip series within a vendor's 'hardware' folder. For example, will default to `samd` if using Sam.mk.

**Example:**

```Makefile
ARCHITECTURE = arm
```

**Requirement:** *Optional*

----

### ARDMK_VENDOR

**Description:**

Board vendor/maintainer/series.

Defaults to `arduino`.

**Example:**

```Makefile
ARDMK_VENDOR = sparkfun
```

**Requirement:** *Optional*

----

### ARDUINO_SKETCHBOOK

**Description:**

Path to `sketchbook` directory.

Usually can be auto-detected from the Arduino `preferences.txt` file or the default `$(HOME)/sketchbook`

**Example:**

```Makefile
ARDUINO_SKETCHBOOK = $(HOME)/sketches
```

**Requirement:** *Optional*

----

### ARDUINO_PREFERENCES_PATH

**Description:**

Path to Arduino `preferences.txt` file.

Usually can be auto-detected as `AUTO_ARDUINO_PREFERENCES` from the defaults:

*	on Linux (1.0):     `$(HOME)/.arduino/preferences.txt`
*	on Linux (1.5+):    `$(HOME)/.arduino15/preferences.txt`
*	on Mac OS X (1.0):  `$(HOME)/Library/Arduino/preferences.txt`
*	on Mac OS X (1.5+): `$(HOME)/Library/Arduino15/preferences.txt`

**Example:**

```Makefile
ARDUINO_PREFERENCES_PATH = $(HOME)/sketches/preferences.txt
```

**Requirement:** *Optional*

----

### ARDUINO_CORE_PATH

**Description:**

Path to standard Arduino core files.

**Example:**

```Makefile
ARDUINO_CORE_PATH = /usr/share/arduino/hardware/arduino/cores/arduino
```

**Requirement:** *Optional*

----

## Sketch related variables

### ARDUINO_LIBS

**Description:**

Any libraries you intend to include.

Usually can be auto-detected from the sketch. Separated by spaces. If the library has a `/utility` folder (like `SD` or `Wire` library), then the utility folder should also be specified.

**Example:**

```Makefile
ARDUINO_LIBS = SD SD/utility Wire Wire/utility
```

**Requirement:** *Optional*

----

### BOARD_TAG

**Description:**

Device type as listed in `boards.txt` or `make show_boards`.

**Example:**

```Makefile
BOARD_TAG = uno or mega2560
```

**Requirement:** *Mandatory*

----

### BOARD_SUB

**Description:**

1.5+ submenu as listed in `boards.txt` or `make show_submenu`.

**Example:**

```Makefile
# diecimila.name=Arduino Duemilanove or Diecimila
BOARD_TAG=diecimila

# diecimila.menu.cpu.atmega168=ATmega168
BOARD_SUB=atmega168
```

**Requirement:** *Mandatory for 1.5+ if using a submenu CPU*

----

### BOARD_CLOCK

**Description:**

Allow selection of f_cpu and fuses specified in `boards.txt` as `{BOARD_TAG}.menu.clock.{BOARD_CLOCK}`.
This works for microprocessor board definitions like ATtiny that specify not only the clock speed but fuse settings as clock overrides.

It also works for f_cpu values specified in `boards.txt` as `{BOARD_TAG}.menu.speed.{BOARD_CLOCK}`.
For example, the Watterott ATmega328PB library [https://github.com/watterott/ATmega328PB-Testing](https://github.com/watterott/ATmega328PB-Testing).

**Example:**

```Makefile
# Select external 16 MHz clock
BOARD_CLOCK=external16
```

**Example:**
```Makefile
# Select 20MHz speed
BOARD_CLOCK=20mhz
```

**Requirement:** *Optional to override main board f_cpu and/or fuse settings.*

----

### MONITOR_PORT

**Description:**

Path to serial (USB) device used for uploading/serial comms.

**Example:**

```Makefile
# Linux
MONITOR_PORT = /dev/ttyUSB0
# or
MONITOR_PORT = /dev/ttyACM0
# Mac OS X
MONITOR_PORT = /dev/cu.usb*
# Windows
MONITOR_PORT = com3
```

**Requirement:** *Mandatory*

----

### FORCE_MONITOR_PORT

**Description:**

Skip the MONITOR_PORT existance check.

**Example:**

```Makefile
# Enable
FORCE_MONITOR_PORT = true
# Disable (default)
undefine FORCE_MONITOR_PORT
```

**Requirement:** *Optional*

----

### USER_LIB_PATH

**Description:**

Directory where additional libraries are stored.

Defaults to `libraries` directory within user's sketchbook.

**Example:**

```Makefile
# Linux
USER_LIB_PATH = $(HOME)/sketchbook/libraries
# For a random project on *nix
USER_LIB_PATH = /path/to/my/project
```

**Requirement:** *Optional*

----

### OBJDIR

**Description:**

Directory where binaries and compiled files are put.

Defaults to `build-$(BOARD_TAG)` in your `Makefile` directory.

**Example:**

```Makefile
OBJDIR = /path/to/my/project-directory/bin
```

**Requirement:** *Optional*

----

### TARGET

**Description:**

What name you would like for generated target files.

Defaults to the name of your current working directory, but with underscores (_) instead of spaces.

**Example:**

```Makefile
TARGET = my-project
```

Will generate targets like `my-project.hex` and `my-project.elf`.

**Requirement:** *Optional*

----

### ALTERNATE_CORE

**Description:**

Non-standard core for Arduino-unsupported chips like the ATtiny.

**Example:**

```Makefile
# HLT core
ALTERNATE_CORE = attiny-master
# tiny core
ALTERNATE_CORE = arduino-tiny
# tiny core 2
ALTERNATE_CORE = tiny2
```

**Requirement:** *Optional*

----

### ARDUINO_VAR_PATH

**Description:**

Path to non-standard core's variant files.

**Example:**

```Makefile
ARDUINO_VAR_PATH = $(HOME)/sketchbook/hardware/arduino-tiny/cores/tiny
```

**Requirement:** *Optional*

----

### CORE

**Description:**

Name of the core *inside* the ALTERNATE_CORE or the standard core.

Usually can be auto-detected as `build.core` from `boards.txt`.

**Example:**

```Makefile
# standard Arduino core (undefine ALTERNATE_CORE)
CORE = arduino
# or
CORE = robot
# tiny core (ALTERNATE_CORE = arduino-tiny)
CORE = tiny
```

**Requirement:** *Optional*

----

### VARIANT

**Description:**

Variant of a standard board design.

Usually can be auto-detected as `build.variant` from `boards.txt`.

**Example:**

```Makefile
VARIANT = leonardo
```

**Requirement:** *Optional*

----

### USB_TYPE

**Description:**

Define Teensy 3.1 usb device type. Default is USB_SERIAL

**Example:**

```Makefile
USB_TYPE = USB_SERIAL
# or
USB_TYPE = USB_HID
# or
USB_TYPE = USB_SERIAL_HID
# or
USB_TYPE = USB_MIDI
# or
USB_TYPE = USB_RAWHID
# or
USB_TYPE = USB_FLIGHTSIM
```

**Requirement:** *Optional*

----

### USB_VID

**Description:**

Override `USB VID` for atmega32u4 boards.

Usually can be auto-detected as `build.vid` from `boards.txt`

**Example:**

```Makefile
USB_VID = 0x2341
```

**Requirement:** *Optional*

----

### USB_PID

**Description:**

Override `USB PID` for atmega32u4 boards.

Usually can be auto-detected as `build.pid` from `boards.txt`

**Example:**

```Makefile
USB_PID = 0x8039
```

**Requirement:** *Optional*

----

### F_CPU

**Description:**

CPU speed in Hz

Usually can be auto-detected as `build.f_cpu` from `boards.txt`, except in
some 1.5+ cores like attiny where there is a clock submenu.

**Example:**

```Makefile
F_CPU = 8000000L
```

**Requirement:** *Optional*

----

### HEX_MAXIMUM_SIZE

**Description:**

Maximum hex file size

Usually can be auto-detected as `upload.maximum_size` from `boards.txt`

**Example:**

```Makefile
HEX_MAXIMUM_SIZE = 14336
```

**Requirement:** *Optional*

----

### MCU

**Description:**

Microcontroller model.

Usually can be auto-detected as `build.mcu` from `boards.txt`

**Example:**

```Makefile
MCU = atmega32u4
```

**Requirement:** *Optional*

----

### MCU_FLAG_NAME

**Description:**

Override default MCU flags.

Defaults to `mmcu`

**Example:**

```Makefile
MCU_FLAG_NAME = mprocessor
```

**Requirement:** *Optional*

----

### MONITOR_BAUDRATE

**Description:**

Baudrate of the serial monitor.

Defaults to `9600` if it can't find it in the sketch `Serial.begin()`

**Example:**

```Makefile
MONITOR_BAUDRATE = 57600
```

**Requirement:** *Optional*

----

## ISP programming variables

### ISP_PROG

**Description:**

Type of ISP. Either a USB device or ArduinoISP protocol.

**Example:**

```Makefile
ISP_PROG = usbasp
# or
ISP_PROG = usbtiny
# or
ISP_PROG = stk500v2
# or
ISP_PROG = stk500v1
```

**Requirement:** *Optional*

----

### ISP_PORT

**Description:**

Device path to ArduinoISP. Not needed for hardware ISP's. Also used to define
bootloader port on SAMD devices.

**Example:**

```Makefile
# Linux
ISP_PORT = /dev/ttyACM0
```

**Requirement:** *Optional*

----

### ISP_LOCK_FUSE_PRE

**Description:**

Bootloader unlock bits.

Usually can be auto-detected from `boards.txt`

**Example:**

```Makefile
ISP_LOCK_FUSE_PRE = 0x3f
```

**Requirement:** *Optional*

----

### ISP_LOCK_FUSE_POST

**Description:**

Bootloader lock bits.

Usually can be auto-detected from `boards.txt`

**Example:**

```Makefile
ISP_LOCK_FUSE_POST = 0xcf
```

**Requirement:** *Optional*

----

### ISP_HIGH_FUSE

**Description:**

`ISP_LOW_FUSE/ISP_EXT_FUSE` - high/low/extended fuse bits.

Usually can be auto-detected from `boards.txt`

**Example:**

```Makefile
ISP_HIGH_FUSE = 0xdf # or 0xff or 0x01
```

**Requirement:** *Optional*

----

### ISP_EEPROM

**Description:**

Whether to upload the EEPROM file or not.

Defaults to `0`

**Example:**

```Makefile
ISP_EEPROM = 1
```

**Requirement:** *Optional*

----

## Compiler/Executable variables

### CC_NAME

**Description:**

C compiler.

Defaults to `avr-gcc`

**Example:**

```Makefile
CC_NAME = pic32-gcc
```

**Requirement:** *Optional*

----

## Compiler/Executable variables

### TOOL_PREFIX

**Description:**

The tool prefix, which gets prepended to the tools like $(TOOL_PREFIX)-gcc, $(TOOL_PREFIX)-g++, etc.
The following tools will be prefixed with '$(TOOL_PREFIX)-':

   * gcc
   * g++
   * as
   * objcopy
   * objdump
   * ar
   * size
   * nm

Defaults to `avr`

**Example:**

```Makefile
TOOL_PREFIX = arm-none-eabi
TOOL_PREFIX = pic32
```

**Requirement:** *Optional*

----

### CXX_NAME

**Description:**

C++ compiler.

Defaults to `avr-g++`

**Example:**

```Makefile
CXX_NAME = pic32-g++
```

**Requirement:** *Optional*

----

### OBJCOPY_NAME

**Description:**

Objcopy utility.

Defaults to `avr-objcopy`

**Example:**

```Makefile
OBJCOPY_NAME = pic32-objcopy
```

**Requirement:** *Optional*

----

### OBJDUMP_NAME

**Description:**

Objdump utility.

Defaults to `avr-objdump`

**Example:**

```Makefile
OBJDUMP_NAME = pic32-objdump
```

**Requirement:** *Optional*

----

### AR_NAME

**Description:**

Archive utility.

Defaults to `avr-ar` unless you're using toolchain > 4.9.0 in which case we use avr-gcc-ar.

**Example:**

```Makefile
AR_NAME = pic32-ar
```

**Requirement:** *Optional*

----

### SIZE_NAME

**Description:**

Size utility.

Defaults to `avr-size`

**Example:**

```Makefile
SIZE_NAME = pic32-size
```

**Requirement:** *Optional*

----

### NM_NAME

**Description:**

Nm utility.

Defaults to `avr-nm`

**Example:**

```Makefile
NM_NAME = pic32-nm
```

**Requirement:** *Optional*

----

### GDB_NAME

**Description:**

GDB utility.

Defaults to `arm-none-eabi-gdb`

**Requirement:** *Optional*

----

### OPTIMIZATION_LEVEL

**Description:**

Linker's `-O` flag

Defaults to `s`, which shouldn't really be changed as it breaks `SoftwareSerial` and usually results in bigger hex files.

**Example:**

```Makefile
OPTIMIZATION_LEVEL = 3
```

**Requirement:** *Optional*

----

### OTHER_LIBS

**Description:**

Additional Linker lib flags, for platform support

Defaults to ""

**Example:**

```Makefile
OTHER_LIBS = -lsomeplatformlib
```

**Requirement:** *Optional*

----

### CFLAGS_STD

**Description:**

Controls, *exclusively*, which C standard is to be used for compilation.

Defaults to `undefined` on 1.0.x or `-std=gnu11` on 1.5+ or if you install AVR toolchain > 4.9.0

Possible values:

*	With `avr-gcc 4.3`, shipped with the 1.0 Arduino IDE:
	*	`undefined`
	*	`-std=c99`
	*	`-std=gnu89` - This is the default for C code
	*	`-std=gnu99`
*	With `avr-gcc 4.7, 4.8 or 4.9`, installed by you or 1.5+ IDE:
	*	`undefined`
	*	`-std=c99`
	*	`-std=c11`
	*	`-std=gnu89`
	*	`-std=gnu99`
	*	`-std=gnu11` - This is the default for C code

For more information, please refer to the [Options Controlling C Dialect](https://gcc.gnu.org/onlinedocs/gcc/C-Dialect-Options.html)

**Example:**

```Makefile
CFLAGS_STD = -std=gnu89
```

**Requirement:** *Optional*

----

### CXXFLAGS_STD

**Description:**

Controls, *exclusively*, which C++ standard is to be used for compilation.

Defaults to `undefined` on 1.0 or `-std=gnu++11` on AVR toolchain > 4.9.0 (e.g. IDE 1.6.10+)

Possible values:

*	With `avr-gcc 4.3`, shipped with the 1.0 Arduino IDE:
	*	`undefined`
	*	`-std=c++98`
	*	`-std=c++0x`
	*	`-std=gnu++98` - This is the default for C code
	*	`-std=gnu++0x`
*	With `avr-gcc 4.7, 4.8 or 4.9`, installed by you or 1.5+ IDE:
	*	`undefined`
	*	`-std=c++98`
	*	`-std=c++11`
	*	`-std=c++1y`
	*	`-std=c++14`
	*	`-std=gnu++98`
	*	`-std=gnu++11` - This is the default for C++ code
	*	`-std=gnu++1y`
	*	`-std=gnu++14`

For more information, please refer to the [Options Controlling C Dialect](https://gcc.gnu.org/onlinedocs/gcc/C-Dialect-Options.html)

**Example:**

```Makefile
CXXFLAGS_STD = -std=gnu++98
```

**Requirement:** *Optional*

----

### CFLAGS

**Description:**

Flags passed to compiler for files compiled as C. Add more flags to this
variable using `+=`.

Defaults to `undefined` on 1.0 or `-flto -fno-fat-lto-objects -fdiagnostics-color=$(DIAGNOSTICS_COLOR_WHEN)` on AVR toolchain > 4.9.0 (e.g. IDE 1.6.10+)

**Example:**

```Makefile
CFLAGS += -my-c-only-flag
```

**Requirement:** *Optional*

----

### CXXFLAGS

**Description:**

Flags passed to the compiler for files compiled as C++. Add more flags to this
variable using `+=`.

Defaults to `-fpermissive -fno-exceptions` on 1.0
or `-fpermissive -fno-exceptions -fno-threadsafe-statics -flto -fno-devirtualize -fdiagnostics-color`
on AVR toolchain > 4.9.0 (e.g. IDE 1.6.10+)

**Example:**

```Makefile
CXXFLAGS += -my-c++-onlyflag
```

**Requirement:** *Optional*

----

### DIAGNOSTICS_COLOR_WHEN

**Description:**

This variable controls the compiler's diagnostics-color setting, as defined
in CFLAGS or CXXFLAGS, on AVR toolchain > 4.9.0.
Supported values are: `always`, `never` and `auto`.
For more details, see: [Options to Control Diagnostic Messages Formatting]
(https://gcc.gnu.org/onlinedocs/gcc-4.9.2/gcc/Language-Independent-Options.html#Language-Independent-Options)

Defaults to `always`.

**Example:**

```Makefile
DIAGNOSTICS_COLOR_WHEN = never
# or
DIAGNOSTICS_COLOR_WHEN = auto
```

**Requirement:** *Optional*

----

### ASFLAGS

**Description:**

Flags passed to compiler for files compiled as assembly (e.g. `.S` files). Add
more flags to this variable using `+=`.

Defaults to all flags required for a typical build.

**Example:**

```Makefile
ASFLAGS += -my-as-only-flag
```

**Requirement:** *Optional*

----

### CPPFLAGS

**Description:**

Flags passed to the C pre-processor (for C, C++ and assembly source files). Add
more flags to this variable using `+=`.

Defaults to all flags required for a typical build.

**Example:**

```Makefile
CPPFLAGS += -DMY_DEFINE_FOR_ALL_SOURCE_TYPES
```

**Requirement:** *Optional*

----

### OVERRIDE_EXECUTABLES

**Description:**

Override the default build tool paths and names.

If OVERRIDE_EXECUTABLES is defined, all tools (`CC`, `CXX`, `AS`,
`OBJCOPY`, `OBJDUMP`, `AR`, `SIZE`, `NM`) must have their paths
explicitly defined. This may be used in the rare case where
overriding a path and/or executable name is required.
The "?=" assignment cannot be used because the executable tags
are already implicitly defined by Make (e.g. $(CC) == cc).

**Example:**

```Makefile
OVERRIDE_EXECUTABLES = 1
CC      = /usr/bin/avr-gcc
CXX     = /usr/bin/avr-g++
AS      = /usr/bin/avr-as
OBJCOPY = /usr/bin/avr-objcopy
OBJDUMP = /usr/bin/avr-objdump
AR      = /usr/bin/avr-ar
SIZE    = /some_path/alternative_avr-size
NM      = /some_path/alternative_avr-nm
```

**Requirement:** *Optional*

----

### MONITOR_CMD

**Description:**

Command to run the serial monitor.

Defaults to `screen`

**Example:**

```Makefile
MONITOR_CMD = minicom
```

**Requirement:** *Optional*

----

### PRE_BUILD_HOOK

**Description:**

Path to shell script to be executed before build. Could be used to automatically
bump revision number for example.

Defaults to `pre-build-hook.sh`

**Example:**

```Makefile
PRE_BUILD_HOOK = $(HOME)/bin/bump-revision.sh
```

**Requirement:** *Optional*

----

## Avrdude setting variables

### AVRDUDE

**Description:**

Path to `avrdude` utility

Usually can be auto-detected within the parent of `AVR_TOOLS_DIR` or in the `$PATH`

**Example:**

```Makefile
AVRDUDE = /usr/bin/avrdude
```

**Requirement:** *Optional*

----

### AVRDUDE_CONF

**Description:**

Path to `avrdude.conf` file

Usually can be auto-detected within the parent of `AVR_TOOLS_DIR`

**Example:**

```Makefile
AVRDUDE_CONF = /etc/avrdude.conf
# or
AVRDUDE_CONF = /usr/share/arduino/hardware/tools/avrdude.conf
```

**Requirement:** *Optional*

----

### AVR_TOOLS_PATH

**Description:**

Directory where tools such as `avrdude`, `avr-g++`, `avr-gcc` etc. are stored.

Usually can be auto-detected from `AVR_TOOLS_DIR/bin`

**Example:**

```Makefile
AVR_TOOLS_PATH = /usr/bin
# or
AVR_TOOLS_PATH = /usr/share/arduino/hardware/tools/avr/bin
```

**Requirement:** *Optional*

----

### ARDUINO_LIB_PATH

**Description:**

Directory where the standard Arduino libraries are stored.

Defaults to `ARDUINO_DIR/libraries`

**Example:**

```Makefile
# Linux
ARDUINO_LIB_PATH = /usr/share/arduino/libraries
```

**Requirement:** *Optional*

----

### ARDUINO_CORE_PATH

**Description:**

Directory where the standard Arduino cores are stored.

Defaults to `ARDUINO_DIR/hardware/arduino/cores/arduino`

**Example:**

```Makefile
ARDUINO_CORE_PATH = /usr/share/arduino/hardware/arduino/cores/robot
```

**Requirement:** *Optional*

----

### ALTERNATE_CORE_PATH

**Description:**

Path to non-standard cores.

Defaults to `ARDUINO_SKETCHBOOK/hardware/ALTERNATE_CORE`

**Example:**

```Makefile
ALTERNATE_CORE_PATH = $(HOME)/sketchbook/hardware/arduino-tiny/cores/tiny
```

**Requirement:** *Optional*

----

### CORE_VER

**Description:**

Alternate core release version. The Arduino board support packages are within
a sub-directory indicated by this define.

Defaults to package current release.

**Example:**

```Makefile
CORE_VER = 1.6.17
```

**Requirement:** *Optional*

----

### CMSIS_DIR

**Description:**

Path to ARM CMSIS. Normally installed as part of ARM  board support.

Defaults to `ARDUINO_PACKAGE_DIR/tools/CMSIS/4.5.0/CMSIS`

**Example:**

```Makefile
CMSIS_DIR = /usr/share/CMSIS
```

**Requirement:** *Optional*

----

### CMSIS_ATMEL_DIR

**Description:**

Path to CMSIS-Atmel directory. Installed with ARM support package.

Defaults to `ARDUINO_PACKAGE_DIR/tools/CMSIS-Atmel/1.1.0/CMSIS`

**Requirement:** *Optional*
----

### BOARDS_TXT

**Description:**

Path to `boards.txt`

Defaults to `ARDUINO_DIR/hardware/arduino/boards.txt`

**Example:**

```Makefile
BOARD_TXT = $(HOME)/sketchbook/hardware/boards.txt
# or
BOARD_TXT = /usr/share/arduino/hardware/arduino/boards.txt
```

**Requirement:** *Optional*

----

### AVRDUDE_ARD_BAUDRATE

**Description:**

Upload speed

Usually can be auto-detected as `upload.speed` from `boards.txt`

**Example:**

```Makefile
AVRDUDE_ARD_BAUDRATE = 19200
```

**Requirement:** *Optional*

----

### AVRDUDE_ARD_PROGRAMMER

**Description:**

Upload protocol

Usually can be auto-detected as `upload.protocol` from `boards.txt`

**Example:**

```Makefile
AVRDUDE_ARD_PROGRAMMER = stk500v1
```

**Requirement:** *Optional*

----

### AVRDUDE_ISP_BAUDRATE

**Description:**

ISP speed if different to `upload.speed`

Defaults to same as `AVRDUDE_ARD_BAUDRATE` or `19200`

**Example:**

```Makefile
AVRDUDE_ISP_BAUDRATE = 19200
```

**Requirement:** *Optional*

----

### AVRDUDE_OPTS

**Description:**

Options to pass to `avrdude`.

Defaults to `-q -V` (quiet, don't verify). User values are not *ANDed* to the defaults, you have to set each option you require.

**Example:**

```Makefile
AVRDUDE_OPTS = -v
```

**Requirement:** *Optional*

----

## Bootloader variables

### BOOTLOADER_FILE

**Description:**

File for bootloader.

Usually can be auto-detected as `bootloader.file` from `boards.txt`

**Example:**

```Makefile
BOOTLOADER_FILE = optiboot_atmega328.hex
```

**Requirement:** *Optional*

----

### BOOTLOADER_PATH

**Description:**

Relative path to bootloader directory.

Usually can be auto-detected as a relative `bootloader.path` from `boards.txt`

Deprecated in 1.5, now part of bootloader.file

**Example:**

```Makefile
BOOTLOADER_PATH = optiboot
# or
BOOTLOADER_PATH = arduino:atmega
```

**Requirement:** *Optional*

----

### BOOTLOADER_PARENT

**Description:**

Absolute path to bootloader file's parent directory.

Defaults to `/usr/share/arduino/hardware/arduino/bootloaders` (Linux)

**Example:**

```Makefile
BOOTLOADER_PARENT = $(HOME)/sketchbook/hardware/promicro/bootloaders
BOOTLOADER_PATH  = caterina
BOOTLOADER_FILE  = Caterina-promicro16.hex
```

Would result in an absolute path to the bootloader hex file of `$(HOME)/sketchbook/hardware/promicro/bootloaders/caterina/Caterina-promicro16.hex`

**Requirement:** *Optional, unless BOOTLOADER_FILE and/or BOOTLOADER_PATH are user-defined*

----

### BOOTLOADER_SIZE

**Description:**

Size of bootloader on ARM devices, ensures correct start address when flashing
application area. Normally parsed from boards.txt

Defaults to `0x2000`

**Requirement:** *Optional*

----

### BOOTLOADER_UNPROTECT

**Description:**

Bootloader unprotect sequence for upload tool. Normally parsed from boards.txt

Defaults to `at91samd bootloader 0`

**Requirement:** *Optional*

----

### BOOTLOADER_PROTECT

**Description:**

Bootloader protect sequence for upload tool. Normally parsed from boards.txt

Defaults to `at91samd bootloader 16384`

**Requirement:** *Optional*

----

### BOOTLOADER_PROTECT_VERIFY

**Description:**

Bootloader protect and verify  sequence for upload tool. Normally parsed from boards.txt

Defaults to `at91samd bootloader`

**Requirement:** *Optional*

----

### BOOTLOADER_UPLOAD_TOOL

**Description:**

Bootloader upload binary to use. Normally parsed from boards.txt.

Defaults to `openocd`

**Requirement:** *Optional*

----

## ChipKIT variables

### MPIDE_DIR

**Description:**

Path to chipKIT MP IDE

Usually can be auto-detected as `AUTO_MPIDE_DIR` from the defaults `/usr/share/mpide` (Linux) or `/Applications/Mpide.app/Contents/Resources/Java` (OSX)

**Example:**

```Makefile
MPIDE_DIR = $(HOME)/mpide
```

**Requirement:** *Optional*

----

### MPIDE_PREFERENCES_PATH

**Description:**

Path to chipKIT `preferences.txt` file.

Usually can be auto-detected as `AUTO_MPIDE_PREFERENCES_PATH` from the defaults `$(HOME)/.mpide/preferences.txt` (Linux) or `$(HOME)/Library/Mpide/preferences.txt` (OSX)

**Example:**

```Makefile
MPIDE_PREFERENCES_PATH = $(HOME)/chipkit/preferences.txt
```

**Requirement:** *Optional*

----

## ARM variables

### UPLOAD_TOOL

**Description:**

Tool to upload binary to device. Normally parsed from boards.txt.

Defaults to `openocd`

**Example:**

```Makefile
UPLOAD_TOOL = gdb
```

**Requirement:** *Optional*

----

### DEBUG

**Description:**

Define to set `DEBUG_FLAGS` and allow stepping of code using GDB.

Defaults to undefined.

**Example:**

```Makefile
DEBUG = 1
```

**Requirement:** *Optional*

----

### GDB_PORT

**Description:**

Server port to use for GDB debugging or upload. Default assumes server running
on localhost but can re-define to use Black Magic Probe serial port.

Defaults to `localhost:3333`

**Example:**

```Makefile
GDB_PORT = /dev/ttyACM0
```

**Requirement:** *Optional*

----

### GDB_OPTS

**Description:**

Optional arguments to parse to GDB command.

Defaults to `-ex "target extended-remote $(GDB_PORT)" -ex "monitor swdp_scan" -ex "attach 1" -ex "load" -d $(OBJDIR) $(TARGET_ELF)`

**Requirement:** *Optional*

----

### GDB_UPLOAD_OPTS

**Description:**

Optional arguments to parse to GDB command when uploading binary only.

Defaults to `GDB_UPLOAD_OPTS = $(GDB_OPTS) -ex "set confirm off" -ex "set target-async off" -ex "set remotetimeout 30" -ex "detach" -ex "kill" -ex "quit"`

**Requirement:** *Optional*

----

### BOSSA

**Description:**

Path to bossac binary.

Can usually be detected from `$ARDUINO_PACKAGE_DIR` /tools subdirectory when ARM
device support is installed.

**Requirement:** *Optional*

----

### BOSSA_OPTS

**Description:**

Flags to pass to bossac command.

Defaults to `-d --info --erase --write --verify --reset`

**Requirement:** *Optional*

----

### OPENOCD

**Description:**

Path to openocd binary.

Can usually be detected from `$ARDUINO_PACKAGE_DIR` /tools subdirectory when ARM
device support is installed.

**Requirement:** *Optional*

----

### OPENOCD_OPTS

**Description:**

Flags to pass to openocd command. If using openocd from non-Arduino
distributions, one should define this with the path to the Arduino openocd script.

Defaults to `-d2`

Example:

```Makefile
OPENOCD_OPTS = $(ARDUINO_PACKAGE_DIR)/$(ARDMK_VENDOR)/tools/openocd/0.9.0-arduino6-static/share/openocd/scripts/ -f $(ARDUINO_PACKAGE_DIR)/$(ARDMK_VENDOR)/hardware/samd/1.6.17/variants/$(VARIANT)/$(OPENOCD_SCRIPT) 
```

**Requirement:** *Optional*

----

## Ctags variables

### TAGS_FILE

**Description:**

Output file name for tags. Defaults to 'tags'.

**Example:**

```Makefile
TAGS_FILE = .tags
```

**Requirement:** *Optional*

----

### CTAGS_OPTS

**Description:**

Additional options to pass to `ctags` command.

**Example:**

```Makefile
# Run ctags in verbose mode
CTAGS_OPTS = -V
```

**Requirement:** *Optional*

----

### CTAGS_CMD

**Description:**

Location of `ctags` binary. Defaults to user path.

**Example:**

```Makefile
CTAGS_CMD = /usr/local/bin/
```

**Requirement:** *Optional*

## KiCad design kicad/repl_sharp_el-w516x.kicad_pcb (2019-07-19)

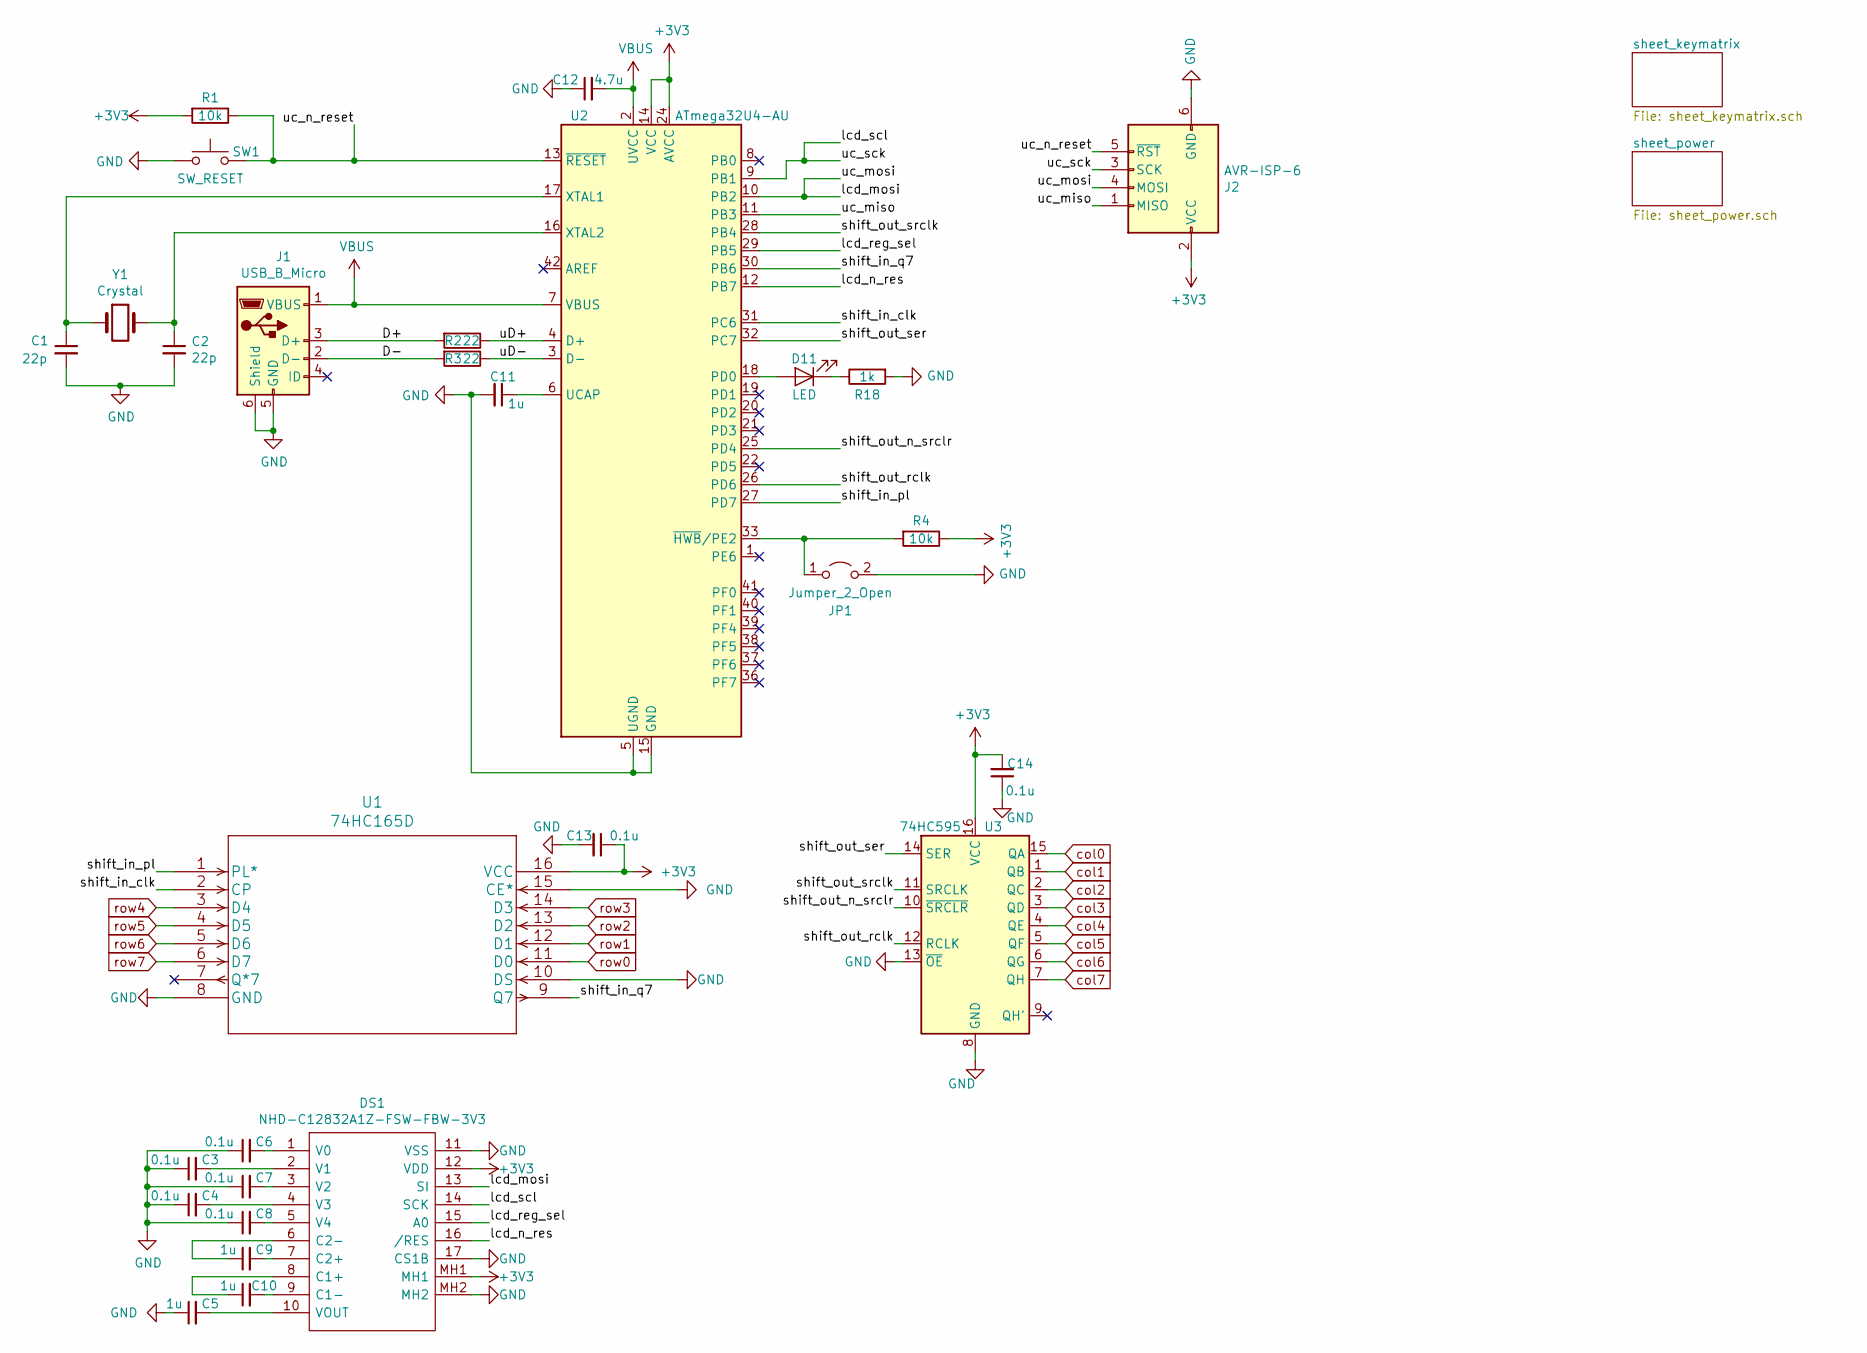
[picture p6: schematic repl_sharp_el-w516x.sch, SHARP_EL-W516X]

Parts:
C1, C2: 22p; C_0603_1608Metric_Pad1.05x0.95mm_HandSolder; part_num CC0603JRNPO9BN220; Digi-Key PN 311-1062-1-ND
C3, C4, C6, C7, C8, C13, C14: 0.1u; C_0603_1608Metric_Pad1.05x0.95mm_HandSolder; part_num CL10B104KO8NNNC; Digi-Key PN 1276-1005-1-ND
C5, C9, C10, C11: 1u; C_0603_1608Metric_Pad1.05x0.95mm_HandSolder; part_num CL10A105KP8NNNC; Digi-Key PN 1276-1182-1-ND
C12: 4.7u; C_0603_1608Metric_Pad1.05x0.95mm_HandSolder; part_num CL10A475KQ8NNNC; Digi-Key PN 1276-1045-1-ND
D11: LED; D_0603_1608Metric_Pad1.05x0.95mm_HandSolder; part_num SML-D12U1WT86; Digi-Key PN SML-D12U1WT86CT-ND
DS1: NHD-C12832A1Z-FSW-FBW-3V3; NHDC12832A1ZFSWFBW3V3; Manufacturer_Part_Number NHD-C12832A1Z-FSW-FBW-3V3; Mouser Part Number 763-C12832A1ZFSWFBW3
J1: USB_B_Micro; USB_Micro-B_Amphenol_10103594-0001LF_Horizontal; part_num 10118192-0001LF; Digi-Key PN 609-4613-1-ND
J2: AVR-ISP-6; PinHeader_2x03_P1.27mm_Vertical_SMD
JP1: Jumper_2_Open; SolderJumper-2_P1.3mm_Open_Pad1.0x1.5mm
R1, R4: 10k; R_0603_1608Metric_Pad1.05x0.95mm_HandSolder; part_num RC0603FR-0710KL; Digi-Key PN 311-10.0KHRCT-ND
R2, R3: 22; R_0603_1608Metric_Pad1.05x0.95mm_HandSolder; part_num RC0603FR-0722RL; Digi-Key PN 311-22.0HRCT-ND
R18: 1k; R_0603_1608Metric_Pad1.05x0.95mm_HandSolder; part_num RC0603FR-071KL; Digi-Key PN 311-1.00KHRCT-ND
SW1: SW_RESET; SW_Push_1P1T_NO_6x6mm_H9.5mm; part_num PTS645SM43SMTR92 LFS; Digi-Key PN CKN9112CT-ND
U1: 74HC165D; SOIC-16_3.9x9.9mm_P1.27mm; part_num 74HC165D\\,652; Digi-Key PN 1727-3782-ND
U2: ATmega32U4-AU; TQFP-44_10x10mm_P0.8mm; part_num ATMEGA32U4-AUR; Digi-Key PN ATMEGA32U4-AURCT-ND
U3: 74HC595; SOIC-16_3.9x9.9mm_P1.27mm; part_num SN74HC595DR; Digi-Key PN 296-14857-1-ND
Y1: Crystal; Crystal_SMD_5032-2Pin_5.0x3.2mm; part_num ECS-80-18-30-JGN-TR; Digi-Key PN XC2103CT-ND

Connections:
+3V3: C13.1, C14.2, DS1.12 (VDD), DS1.MH1, J2.2 (VCC), R1.2, R4.1, U1.16 (VCC), U2.14 (VCC), U2.24 (AVCC), U2.34 (VCC), U2.44 (AVCC), U3.16 (VCC); also elsewhere on the board
/D+: J1.3 (D+), R2.2
/D-: J1.2 (D-), R3.2
/lcd_mosi: DS1.13 (SI), J2.4 (MOSI), U2.10 (PB2)
/lcd_n_res: DS1.16 (/RES), U2.12 (PB7)
/lcd_reg_sel: DS1.15 (A0), U2.29 (PB5)
/lcd_scl: DS1.14 (SCK), J2.3 (SCK), U2.9 (PB1)
/shift_in_clk: U1.2 (CP), U2.31 (PC6)
/shift_in_pl: U1.1 (PL*), U2.27 (PD7)
/shift_in_q7: U1.9 (Q7), U2.30 (PB6)
/shift_out_n_srclr: U2.25 (PD4), U3.10 (~SRCLR)
/shift_out_rclk: U2.26 (PD6), U3.12 (RCLK)
/shift_out_ser: U2.32 (PC7), U3.14 (SER)
/shift_out_srclk: U2.28 (PB4), U3.11 (SRCLK)
/uD+: R2.1, U2.4 (D+)
/uD-: R3.1, U2.3 (D-)
/uc_miso: J2.1 (MISO), U2.11 (PB3)
/uc_n_reset: J2.5 (~RST), R1.1, SW1.2, U2.13 (~RESET)
GND: C1.2, C2.2, C3.1, C4.1, C5.1, C6.1, C7.1, C8.1, C11.2, C12.1, C13.2, C14.1, DS1.11 (VSS), DS1.17 (CS1B), DS1.MH2, J1.5 (GND), J1.6 (Shield), J2.6 (GND), JP1.2 (B), R18.2, SW1.1, U1.8 (GND), U1.10 (DS), U1.15 (CE*), U2.5 (UGND), U2.15 (GND), U2.23 (GND), U2.35 (GND), U2.43 (GND), U3.8 (GND), U3.13 (~OE); also elsewhere on the board
unnamed: C1.1, U2.17 (XTAL1), Y1.1
unnamed: C2.1, U2.16 (XTAL2), Y1.2
unnamed: C3.2, DS1.2 (V1)
unnamed: C4.2, DS1.4 (V3)
unnamed: C5.2, DS1.10 (VOUT)
unnamed: C6.2, DS1.1 (V0)
unnamed: C7.2, DS1.3 (V2)
unnamed: C8.2, DS1.5 (V4)
unnamed: C9.1, DS1.6 (C2-)
unnamed: C9.2, DS1.7 (C2+)
unnamed: C10.1, DS1.8 (C1+)
unnamed: C10.2, DS1.9 (C1-)
unnamed: C11.1, U2.6 (UCAP)
unnamed: D11.1 (K), R18.1
unnamed: D11.2 (A), U2.18 (PD0)
unnamed: JP1.1 (A), R4.2, U2.33 (~HWB~/PE2)
VBUS: C12.2, J1.1 (VBUS), U2.2 (UVCC), U2.7 (VBUS); also elsewhere on the board
col0: U3.15 (QA); also elsewhere on the board
col1: U3.1 (QB); also elsewhere on the board
col2: U3.2 (QC); also elsewhere on the board
col3: U3.3 (QD); also elsewhere on the board
col4: U3.4 (QE); also elsewhere on the board
col5: U3.5 (QF); also elsewhere on the board
col6: U3.6 (QG); also elsewhere on the board
col7: U3.7 (QH); also elsewhere on the board
row0: U1.11 (D0); also elsewhere on the board
row1: U1.12 (D1); also elsewhere on the board
row2: U1.13 (D2); also elsewhere on the board
row3: U1.14 (D3); also elsewhere on the board
row4: U1.3 (D4); also elsewhere on the board
row5: U1.4 (D5); also elsewhere on the board
row6: U1.5 (D6); also elsewhere on the board
row7: U1.6 (D7); also elsewhere on the board

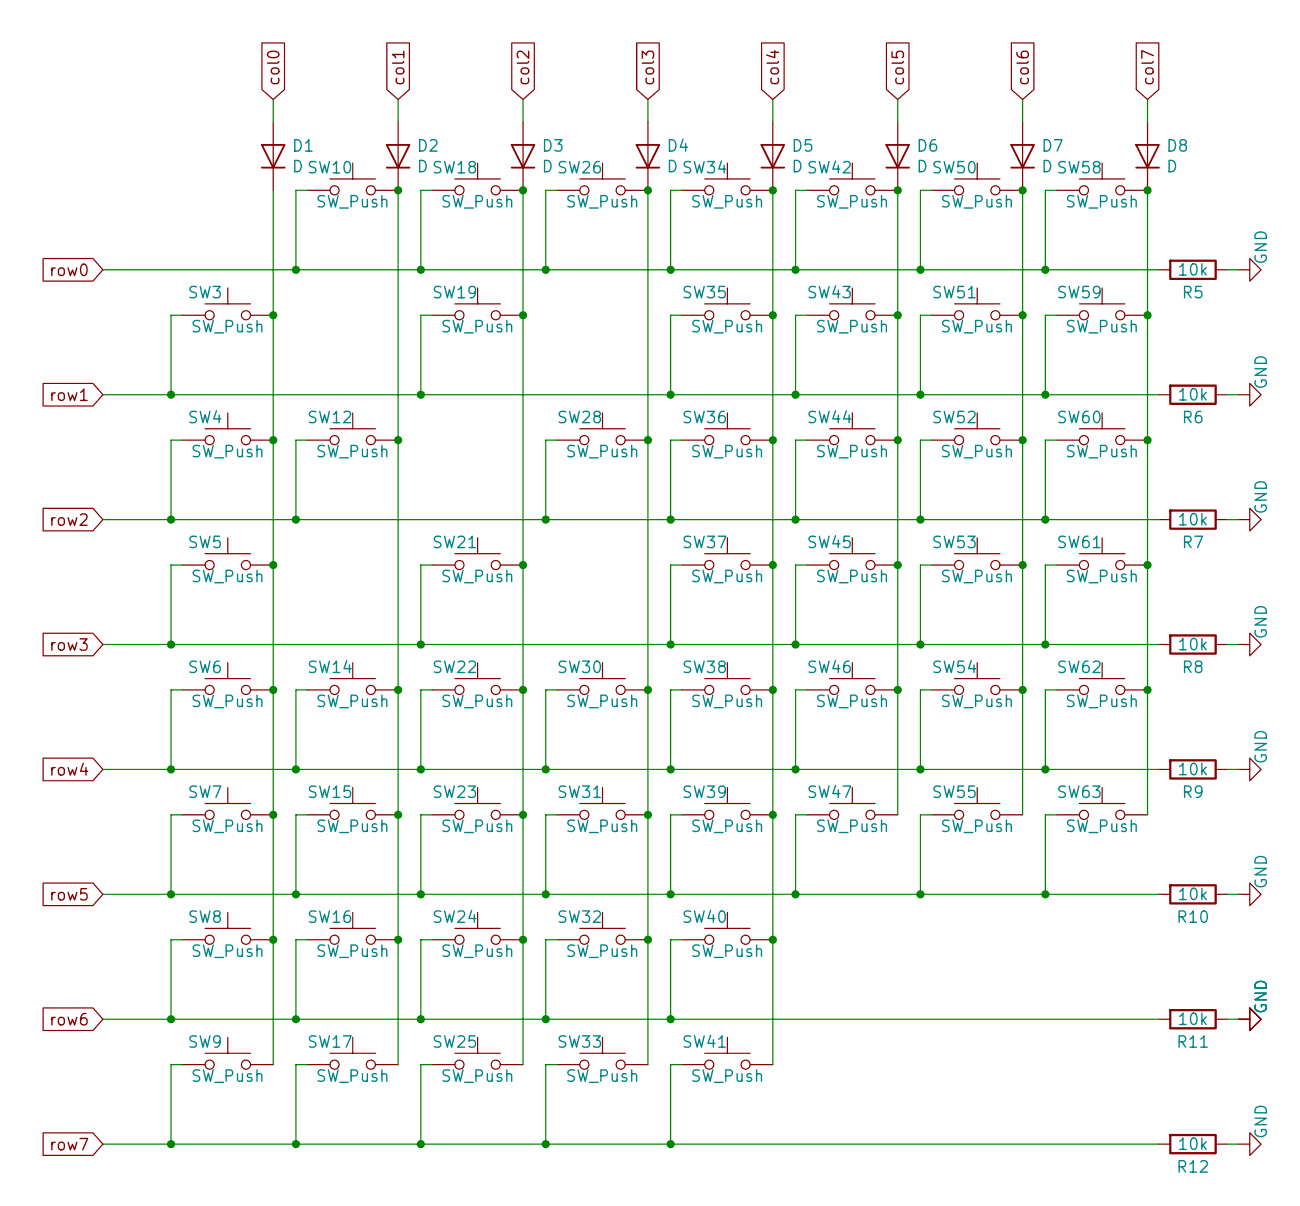
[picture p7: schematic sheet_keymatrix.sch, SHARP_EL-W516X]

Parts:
D1, D2, D3, D4, D5, D6, D7, D8: D; D_0603_1608Metric_Pad1.05x0.95mm_HandSolder; part_num TS4148C RZG; Digi-Key PN TS4148CRZGCT-ND
R5, R6, R7, R8, R9, R10, R11, R12: 10k; R_0603_1608Metric_Pad1.05x0.95mm_HandSolder; part_num RC0603FR-0710KL; Digi-Key PN 311-10.0KHRCT-ND
SW3, SW4, SW5, SW10, SW18, SW19, SW21, SW26, SW34, SW35, SW36, SW37: SW_Push; btn_rect
SW6, SW7, SW8, SW9, SW14, SW15, SW16, SW17, SW22, SW23, SW24, SW25, SW30, SW31, SW32, SW33, SW38, SW39, SW40, SW41, SW42, SW43, SW44, SW45, SW46, SW47, SW50, SW51, SW52, SW53, SW54, SW55, SW58, SW59, SW60, SW61, SW62, SW63: SW_Push; btn_circular
SW12, SW28: SW_Push; btn_long_rect

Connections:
GND: R5.1, R6.1, R7.1, R8.1, R9.1, R10.1, R11.1, R12.1; also elsewhere on the board
unnamed: D1.1 (K), SW3.2, SW4.2, SW5.2, SW6.2, SW7.2, SW8.2, SW9.2
unnamed: D2.1 (K), SW10.2, SW12.2, SW14.2, SW15.2, SW16.2, SW17.2
unnamed: D3.1 (K), SW18.2, SW19.2, SW21.2, SW22.2, SW23.2, SW24.2, SW25.2
unnamed: D4.1 (K), SW26.2, SW28.2, SW30.2, SW31.2, SW32.2, SW33.2
unnamed: D5.1 (K), SW34.2, SW35.2, SW36.2, SW37.2, SW38.2, SW39.2, SW40.2, SW41.2
unnamed: D6.1 (K), SW42.2, SW43.2, SW44.2, SW45.2, SW46.2, SW47.2
unnamed: D7.1 (K), SW50.2, SW51.2, SW52.2, SW53.2, SW54.2, SW55.2
unnamed: D8.1 (K), SW58.2, SW59.2, SW60.2, SW61.2, SW62.2, SW63.2
col0: D1.2 (A); also elsewhere on the board
col1: D2.2 (A); also elsewhere on the board
col2: D3.2 (A); also elsewhere on the board
col3: D4.2 (A); also elsewhere on the board
col4: D5.2 (A); also elsewhere on the board
col5: D6.2 (A); also elsewhere on the board
col6: D7.2 (A); also elsewhere on the board
col7: D8.2 (A); also elsewhere on the board
row0: R5.2, SW10.1, SW18.1, SW26.1, SW34.1, SW42.1, SW50.1, SW58.1; also elsewhere on the board
row1: R6.2, SW3.1, SW19.1, SW35.1, SW43.1, SW51.1, SW59.1; also elsewhere on the board
row2: R7.2, SW4.1, SW12.1, SW28.1, SW36.1, SW44.1, SW52.1, SW60.1; also elsewhere on the board
row3: R8.2, SW5.1, SW21.1, SW37.1, SW45.1, SW53.1, SW61.1; also elsewhere on the board
row4: R9.2, SW6.1, SW14.1, SW22.1, SW30.1, SW38.1, SW46.1, SW54.1, SW62.1; also elsewhere on the board
row5: R10.2, SW7.1, SW15.1, SW23.1, SW31.1, SW39.1, SW47.1, SW55.1, SW63.1; also elsewhere on the board
row6: R11.2, SW8.1, SW16.1, SW24.1, SW32.1, SW40.1; also elsewhere on the board
row7: R12.2, SW9.1, SW17.1, SW25.1, SW33.1, SW41.1; also elsewhere on the board

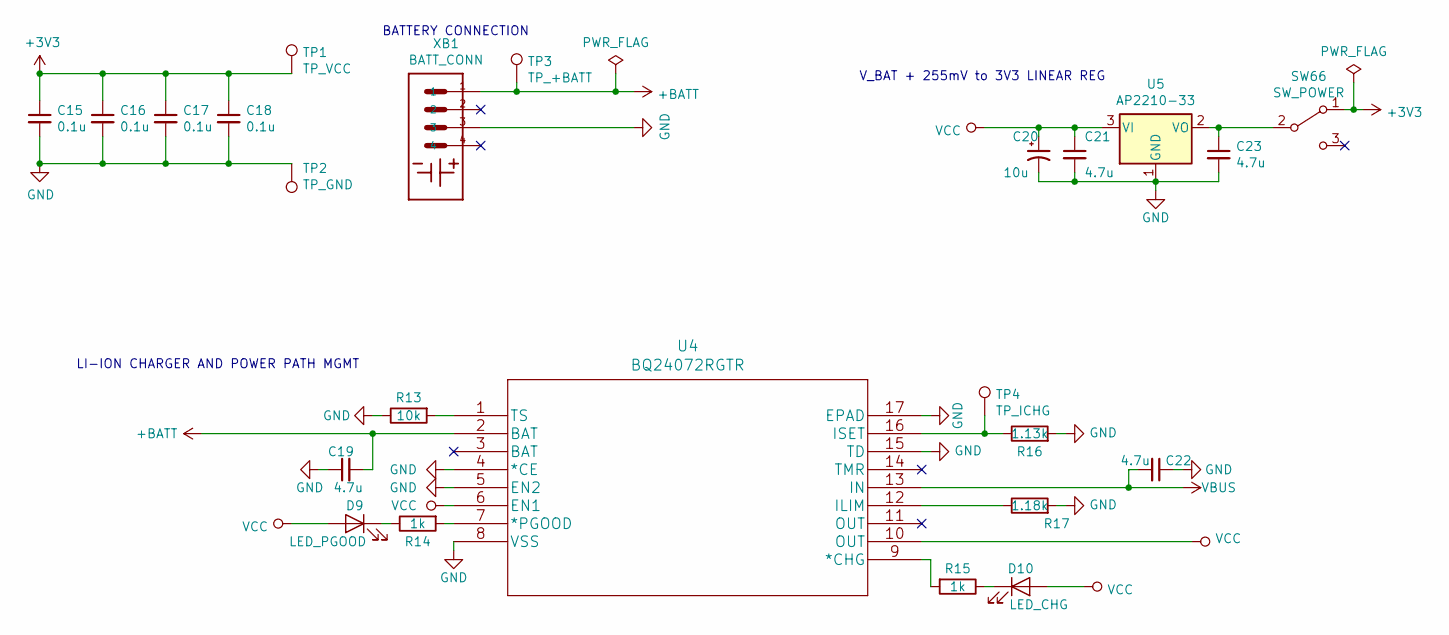
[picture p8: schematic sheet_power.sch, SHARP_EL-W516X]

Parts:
C15, C16, C17, C18: 0.1u; C_0603_1608Metric_Pad1.05x0.95mm_HandSolder; part_num CL10B104KO8NNNC; Digi-Key PN 1276-1005-1-ND
C19, C21, C22, C23: 4.7u; C_0603_1608Metric_Pad1.05x0.95mm_HandSolder; part_num CL10A475KQ8NNNC; Digi-Key PN 1276-1045-1-ND
C20: 10u; CP_Elec_4x5.3; part_num UZR1C100MCL1GB; Digi-Key PN 493-10106-1-ND
D9: LED_PGOOD; LED_0603_1608Metric_Pad1.05x0.95mm_HandSolder; part_num SML-D12U1WT86; Digi-Key PN SML-D12U1WT86CT-ND
D10: LED_CHG; LED_0603_1608Metric_Pad1.05x0.95mm_HandSolder; part_num SML-D12U1WT86; Digi-Key PN SML-D12U1WT86CT-ND
R13: 10k; R_0603_1608Metric_Pad1.05x0.95mm_HandSolder; part_num RC0603FR-0710KL; Digi-Key PN 311-10.0KHRCT-ND
R14, R15: 1k; R_0603_1608Metric_Pad1.05x0.95mm_HandSolder; part_num RC0603FR-071KL; Digi-Key PN 311-1.00KHRCT-ND
R16: 1.13k; R_0603_1608Metric_Pad1.05x0.95mm_HandSolder; part_num RC0603FR-071K13L; Digi-Key PN 311-1.13KHRCT-ND
R17: 1.18k; R_0603_1608Metric_Pad1.05x0.95mm_HandSolder; part_num RC0603FR-071K18L; Digi-Key PN 311-1.18KHRCT-ND
SW66: SW_POWER; SW_SPDT_CK-JS102011SAQN; part_num JS102011SAQN; Digi-Key PN 401-1999-1-ND
TP1: TP_VCC; TestPoint_Pad_1.0x1.0mm
TP2: TP_GND; TestPoint_Pad_1.0x1.0mm
TP3: TP_+BATT; TestPoint_Pad_1.0x1.0mm
TP4: TP_ICHG; TestPoint_Pad_1.0x1.0mm
U4: BQ24072RGTR; part_num BQ24072RGTR; Digi-Key PN 296-38871-1-ND
U5: AP2210-33; SOT-23; part_num AP2210N-3.3TRG1; Digi-Key PN AP2210N-3.3TRG1DICT-ND
XB1: BATT_CONN; BAT_009155004541006; part_num 009155004541006; Digi-Key PN 478-5452-1-ND

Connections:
+3V3: C15.1, C16.1, C17.1, C18.1, SW66.1 (A), TP1.1; also elsewhere on the board
+BATT: C19.2, TP3.1, U4.2 (BAT), XB1.1
GND: C15.2, C16.2, C17.2, C18.2, C19.1, C20.2, C21.2, C22.1, C23.2, R13.1, R16.2, R17.2, TP2.1, U4.4 (*CE), U4.5 (EN2), U4.8 (VSS), U4.15 (TD), U4.17 (EPAD), U5.1 (GND), XB1.3; also elsewhere on the board
unnamed: C23.1, SW66.2 (B), U5.2 (VO)
unnamed: D9.1 (K), R14.1
unnamed: D10.1 (K), R15.1
unnamed: R13.2, U4.1 (TS)
unnamed: R14.2, U4.7 (*PGOOD)
unnamed: R15.2, U4.9 (*CHG)
unnamed: R16.1, TP4.1, U4.16 (ISET)
unnamed: R17.1, U4.12 (ILIM)
VBUS: C22.2, U4.13 (IN); also elsewhere on the board
VCC: C20.1, C21.1, D9.2 (A), D10.2 (A), U4.6 (EN1), U4.10 (OUT), U5.3 (VI)

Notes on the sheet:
V_BAT + 255mV to 3V3 LINEAR REG
BATTERY CONNECTION
LI-ION CHARGER AND POWER PATH MGMT

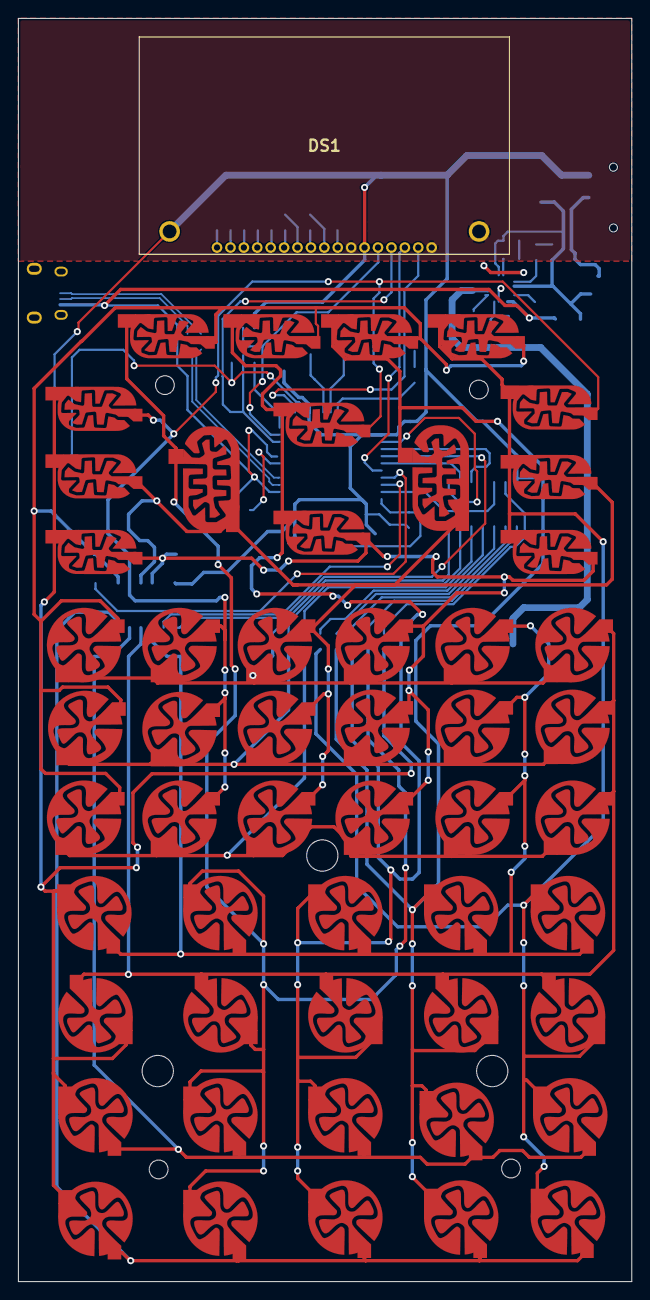
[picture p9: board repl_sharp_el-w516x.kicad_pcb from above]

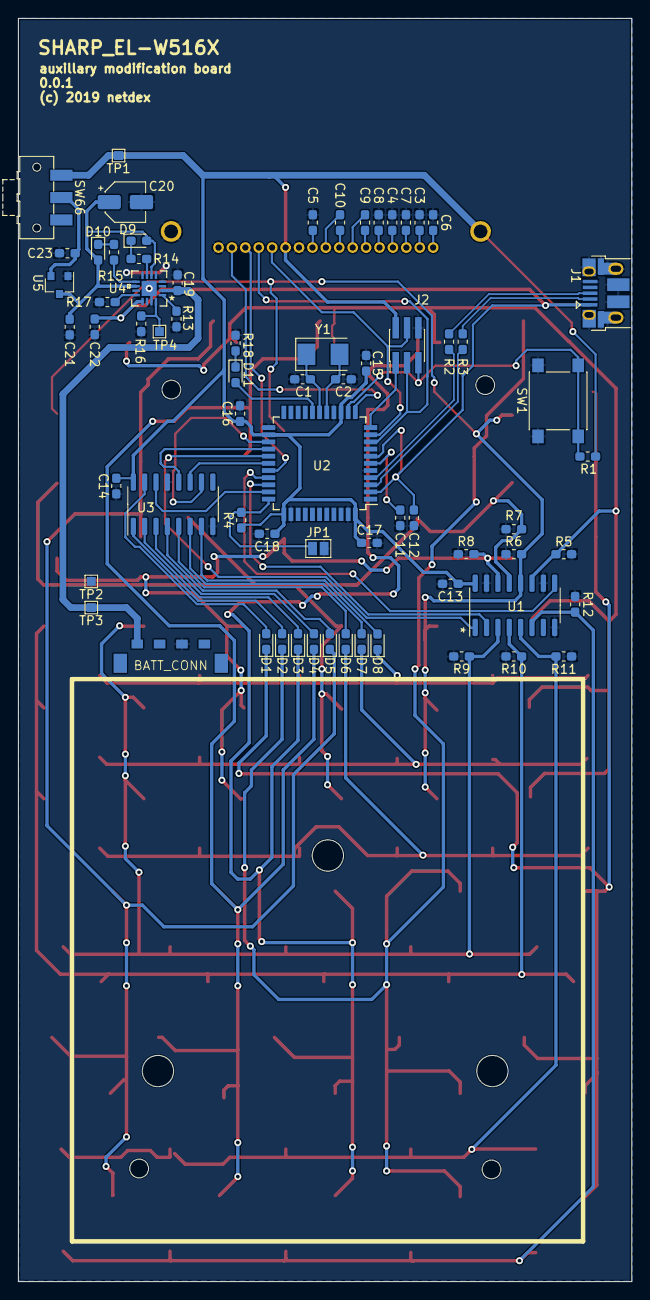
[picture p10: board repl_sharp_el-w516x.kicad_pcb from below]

Board: 2 copper layers, 68.6 x 141.2 mm, 121 parts (68 on the bottom side), 70 nets.

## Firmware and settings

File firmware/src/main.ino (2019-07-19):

#include <math.h>
#include <stdlib.h>

#include "ST7565.h"
#include "tinyexpr.h"

#include "bootloader.hpp"
#include "expr_buffer.hpp"
#include "ic74hc165.hpp"
#include "ic74hc595.hpp"
#include "key_def.hpp"
#include "matrix_controller.hpp"

#define LCD_RST 11  // Reset signal
#define LCD_RS 9    // Register select signal

#define SI_CLK 5  // shift in, clk
#define SI_Q7 10  // shift in, input
#define SI_PL 6   // shift in, parallel load

#define SO_RCLK 12    // shift out, stage clk
#define SO_SRCLK 8    // shift out, final stage clk
#define SO_SER 13     // shift out, output
#define SO_N_SRCLR 4  // shift out, reset

ST7565 glcd(LCD_RS, LCD_RST);

const ic74hc165 srin(SI_CLK, SI_Q7, SI_PL);
const ic74hc595 srout(SO_RCLK, SO_SRCLK, SO_SER, SO_N_SRCLR);

matrix_controller mat_ctrl(srin, srout);

expr_buffer expr;
bool secondf = false;

void draw_buffer() {
  glcd.clear();
  glcd.drawstring(0, 0, expr.buffer);
  int y = expr.pos / 21;
  int x = (expr.pos % 21) * 6;
  glcd.drawline(x, y, x, y + 8, 1);
  if (secondf) glcd.fillrect(120, 30, 2, 2, 1);
  glcd.display();
}

void setup() {
  CLKPR = (1 << CLKPCE);
  CLKPR = (0 << CLKPS3) | (0 << CLKPS2) | (0 << CLKPS1) | (0 << CLKPS0);
  Serial.begin(9600);

  srin.init();
  srout.init();

  // initialize and set the contrast to 0x18
  glcd.begin(0x20);

  draw_buffer();
}

void loop() {

  key k = mat_ctrl.poll();

  const char *kstr = secondf ? KEY_STR_2ND(k) : KEY_STR(k);
  if (kstr) {
    expr.insert(kstr);
    secondf = false;
    draw_buffer();
  }

  switch (k) {
    case KEY_MODE:
      glcd.clear();
      glcd.drawstring(0,1,"       DFU MODE");
      glcd.display();
      delay(10);
      bootloader_jump();
      break;
    case KEY_EQ_1:
    case KEY_EQ_2: {
      int error;
      double result = te_interp(expr.buffer, &error);
      glcd.clear();

      char error_str[64];
      if (error) {
        sprintf(error_str, "error at position %d", error);
      } else {
        sprintf(error_str, "=%lf", result);
      }
      glcd.drawstring(0, 0, error_str);
      glcd.display();
      while (mat_ctrl.poll() != KEY_ON_C) {
        delay(10);
      }
      expr.reset();
      draw_buffer();
    } break;
    case KEY_BS:
      expr.backspace();
      draw_buffer();
      break;
    case KEY_LEFT:
      expr.move(expr.pos - 1);
      draw_buffer();
      break;
    case KEY_RIGHT:
      expr.move(expr.pos + 1);
      draw_buffer();
      break;
    case KEY_ON_C:
      expr.reset();
      draw_buffer();
      break;
    case KEY_2ND_F:
      secondf = !secondf;
      draw_buffer();
      break;
  }
  delay(20);
}

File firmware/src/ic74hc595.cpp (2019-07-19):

#include "ic74hc595.hpp"

void ic74hc595::init() const {
  pinMode(rclk, OUTPUT);
  pinMode(srclk, OUTPUT);
  pinMode(ser, OUTPUT);
  pinMode(srclr_n, OUTPUT);
  digitalWrite(rclk, LOW);
  digitalWrite(srclk, LOW);
  digitalWrite(ser, LOW);
}

void ic74hc595::write(byte data) const {
  digitalWrite(srclr_n, HIGH);
  digitalWrite(srclk, LOW);
  shiftOut(ser,srclk, MSBFIRST, data);
  digitalWrite(rclk, LOW);
  digitalWrite(rclk, HIGH);
}

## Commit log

2019-06-06 pcb: initial design barring supply power and display
    [repl_sharp_el-w516x.kicad_pcb, repl_sharp_el-w516x.sch]
2019-06-17 kicad: update schematic and pcb
    [repl_sharp_el-w516x.kicad_pcb, repl_sharp_el-w516x.sch, sheet_keymatrix.sch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]
2019-06-30 kicad: completed partial layout
    [repl_sharp_el-w516x-B_Cu.gbr, repl_sharp_el-w516x-B_Mask.gbr, repl_sharp_el-w516x-B_Paste.gbr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]
2019-07-05 kicad: finalize design
    [repl_sharp_el-w516x.kicad_pcb, repl_sharp_el-w516x.sch]
2019-07-07 kicad: design after production
    [repl_sharp_el-w516x-B_Cu.gbr, repl_sharp_el-w516x-B_Mask.gbr, repl_sharp_el-w516x-B_Paste.gbr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]
2019-07-07 kicad: finalize device BOM
    [repl_sharp_el-w516x.kicad_pcb, repl_sharp_el-w516x.sch, sheet_keymatrix.sch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]
2019-07-08 kicad: fix virtual component
    [repl_sharp_el-w516x.kicad_pcb, repl_sharp_el-w516x.sch, repl_sharp_el-w516x.xlsx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]
2019-07-19 firmware: first implementation with symbolic math
    [repl_sharp_el-w516x.kicad_pcb, repl_sharp_el-w516x.old.xlsx, repl_sharp_el-w516x.xlsx]

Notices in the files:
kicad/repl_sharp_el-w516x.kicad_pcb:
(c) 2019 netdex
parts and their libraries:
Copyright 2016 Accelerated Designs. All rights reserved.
